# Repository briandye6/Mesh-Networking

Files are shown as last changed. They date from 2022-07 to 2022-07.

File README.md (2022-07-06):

# ENIGMA Mesh Networking Design Project
This repository was designed to be used with the STM32F091RCT ARM Cortex microcontroller.

### Repository Layout:
| File | Purpose |
| --- |:---|
| src/main.c | Contains the all interrupt setup functions, interrupt service routines, and GPS, Battery helper functions |
| src/SPI.c | SPI initialization, write, and read for RFM69HCW Radio and MP2202 TFT Display |
| src/I2C.c | I2C initialization, write, and read for Sparkfun Battery Baby Sitter and SAM-M8Q GPS module|
| src/bluetooth.c|  UART initialization, write, and read for HM-19 bluetooth module|
| src/lcd.c|  Helper functions to communicate with MP2202 TFT Display|
| src/RFM69.c|  Helper functions to communicate with RFM69HCW Radio|
| src/STPswitch.c|  Helper functions to create and facilitate a MESH Spanning Tree Protocol|
| src/list.c| Doubly Linked List Data Structure for forwarding table|

### User Interace: Progressive Web Application
https://enigmaterminal.net/

### Final Design Review Presentation Link with VIDEO DEMONSTRATION
https://purdue0-my.sharepoint.com/:p:/g/personal/dye28_purdue_edu/Ee8eXgqAICREm-nx36Vz36ABuLT1QJ_dSffJ5avcmjQzwg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

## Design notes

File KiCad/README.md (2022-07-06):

# KiCad files for Printed Circuit Board (PCB) Design

### What is KiCad?
KiCad is a free software that facilitates the design and simulation of electronic hardware.

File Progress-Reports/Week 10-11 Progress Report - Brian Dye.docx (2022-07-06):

# Senior Design Progress Report

Student: | Brian Dye | Team: | 20 ENIGMA
Semester: | Spring 2022 | Position: | Team Leader
Week: | 10 and 11 | Hours: | 40

# Progress Description

Over Spring Break, I successfully interfaced the SparkFun Battery Baby Sitter and the Ublox SAM-M8Q GPS module. Both share the same I2C bus. Now we can accurately demonstrate the battery level remaining and show the GPS coordinates of our location:

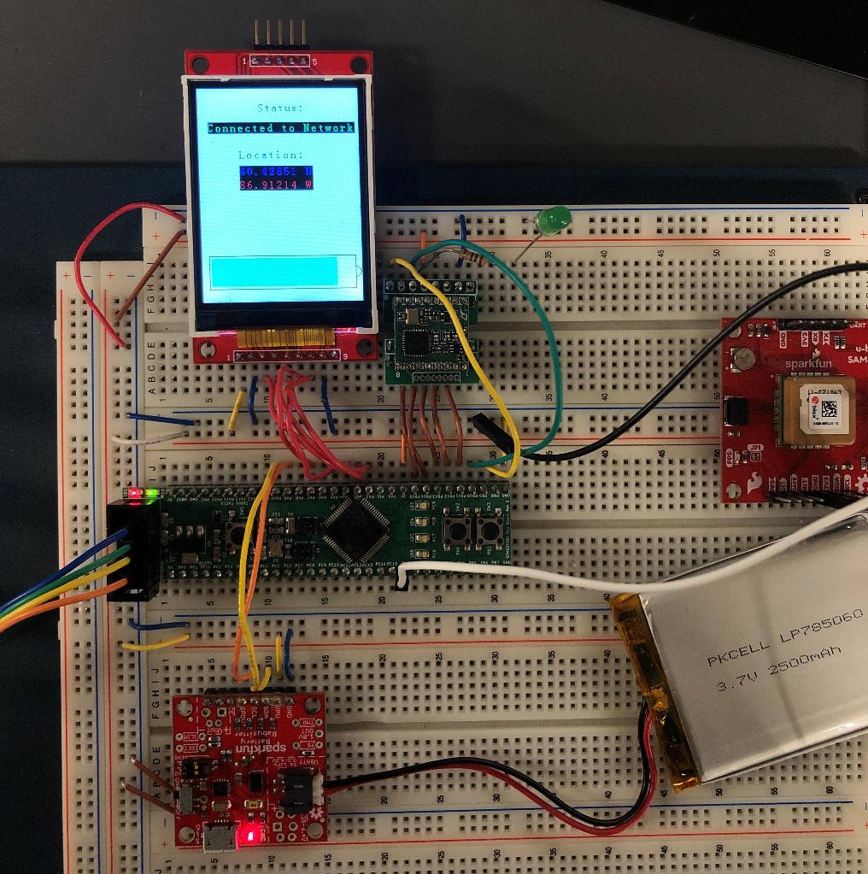
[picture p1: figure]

An issue that I ran into was that I did not have the correct understanding of the frequency that the I2C clock operated at. My initial understanding was that it was operating at 48 MHz which is the same frequency that the STM32F091 clock is operating. The GPS did not “fuss” about the Data Setup Time or Data Hold Time in the I2C communication. However, the Battery Babysitter did. All my calculations for the timing register were incorrect due to my assumption that the I2C clock was operating at 48 MHz. I came to realize the clock is actually operating at 8 MHz from reading the old lecture notes from ECE-362. Once I made the correct changes to the timing register of the I2C, it works flawlessly. Now, the Battery Babysitter and GPS module can share an I2C bus to communicate seamlessly. This accomplishment concludes the serial communication interfacing required to implement the functionality that we desire from each node in our project. Now, I plan to start working on the routing algorithms required to create a self-forming, self-organizing, distributed mobile ad-hoc network.

Module | Function | Serial Protocol
RFM69HCW | Send & Receive Data for mobile network | Serial Peripheral Interface (SPI)
MP2022 TFT LCD Screen | Demonstrate Coordinates, Network Status and Battery Level to User | Serial Peripheral Interface (SPI)
HM-19 | Interface each node with Bluetooth Device | Universal Asynchronous Receiver Transmitter (UART)
Battery Babysitter | Charge and monitor LiPo battery | Inter-Integrated Circuit (I2C)
SAM-M8Q | Provide GPS coordinates | Inter-Integrated Circuit (I2C)

# Printed Circuit Board (PCB)

PCB is done and ordered. We ran into the issue that the edge cut was not properly in the Gerber and Drill files. So, we had to fix the issue and resubmit the files to JCLPCB and it is currently on it’s way. I ordered 10 boards. We have enough modules to make 5 nodes. Extras are for mistakes that potentially occur while soldering components to boards.

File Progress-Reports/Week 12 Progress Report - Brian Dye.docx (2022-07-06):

# Senior Design Progress Report

Student: | Brian Dye | Team: | 20 ENIGMA
Semester: | Spring 2022 | Position: | Team Leader
Week: | 12 | Hours: | 20

# Progress Description

This week I successfully created the push button interrupt for the LCD. Creating this functionality was necessary to reduce power consumption and extend battery life. When the user wants to know network status, battery level, and current GPS coordinates they can push a button which will 1) power the LCD screen and 2) create an external interrupt that sends the most recent network, battery, and GPS coordinates that have been made available by the respective modules. Instead of fetching fresh status updates from modules within the interrupt service routine, I decided to invoke a timer interrupt every 5 seconds to fetch fresh information from each module. Then when the user wants to see information on the LCD screen, it displays the latest information instead of making various serial communications to modules. This proved to be much more efficient.

I also worked on the communication interface between the host device and node. Nathan and I decided to take a conservative approach and send fixed data size packets over Bluetooth. When a packet arrives, it will generate a DMA interrupt which invokes an ISR. In the ISR, the STM32 will read the first n bytes for the command and take appropriate action. This is demonstrated below:

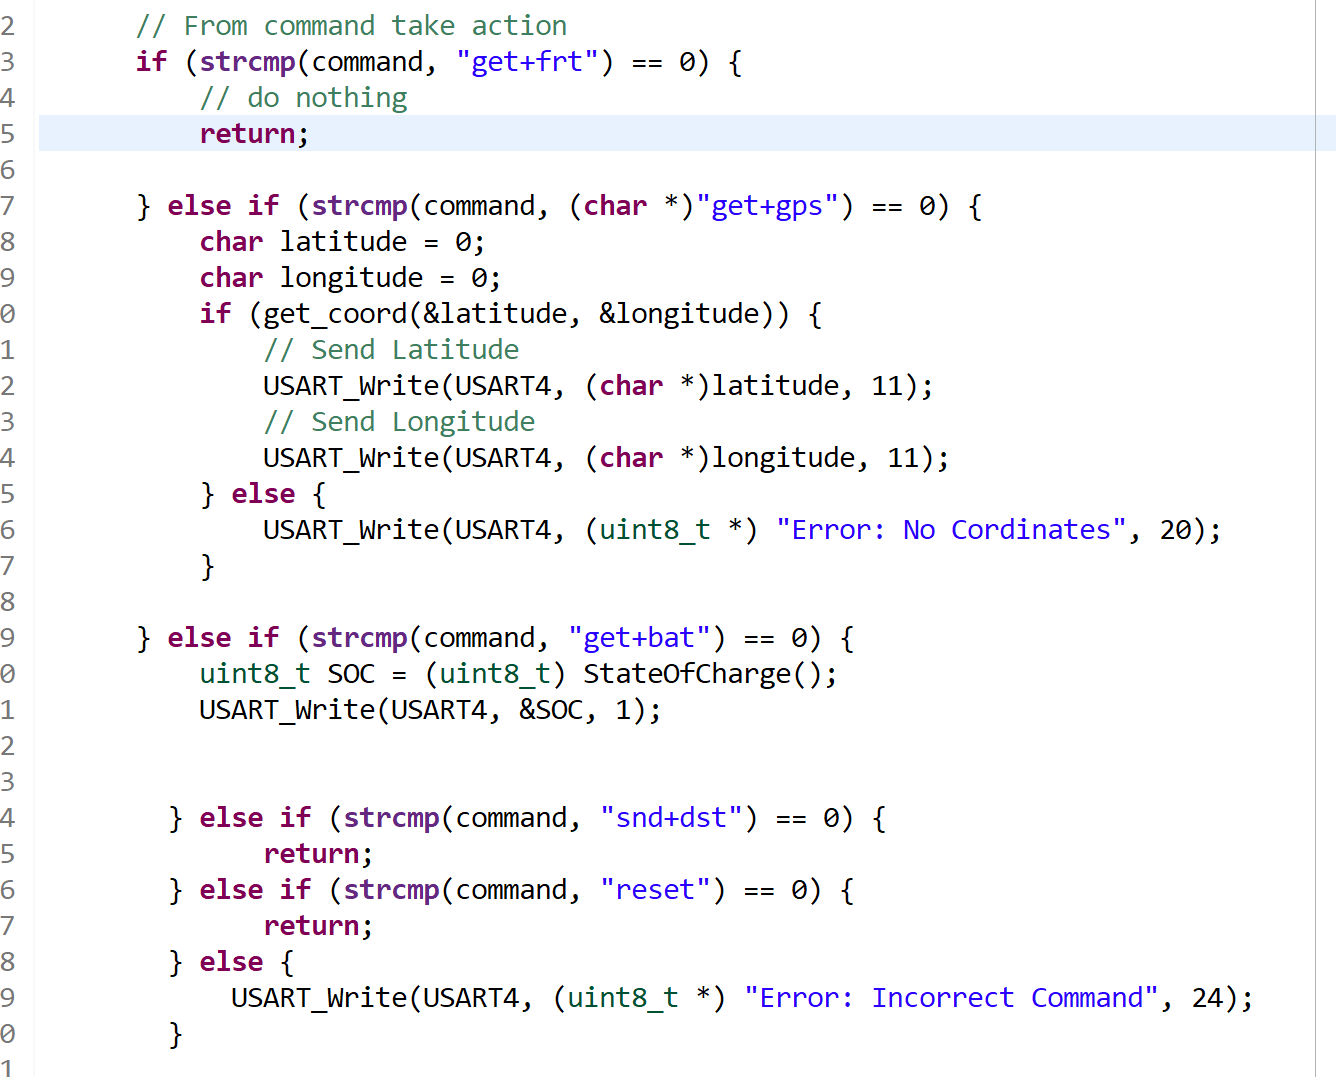
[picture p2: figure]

# Printed Circuit Board (PCB)

PCB has arrived. We have made plans to start soldering the PCB tomorrow on Saturday 04/02/2022. Our current plan is to solder power components, then STM32F0 microcontroller, and finally each individual module. Between soldering each component, we plan on performing tests to ensure proper connections were established.

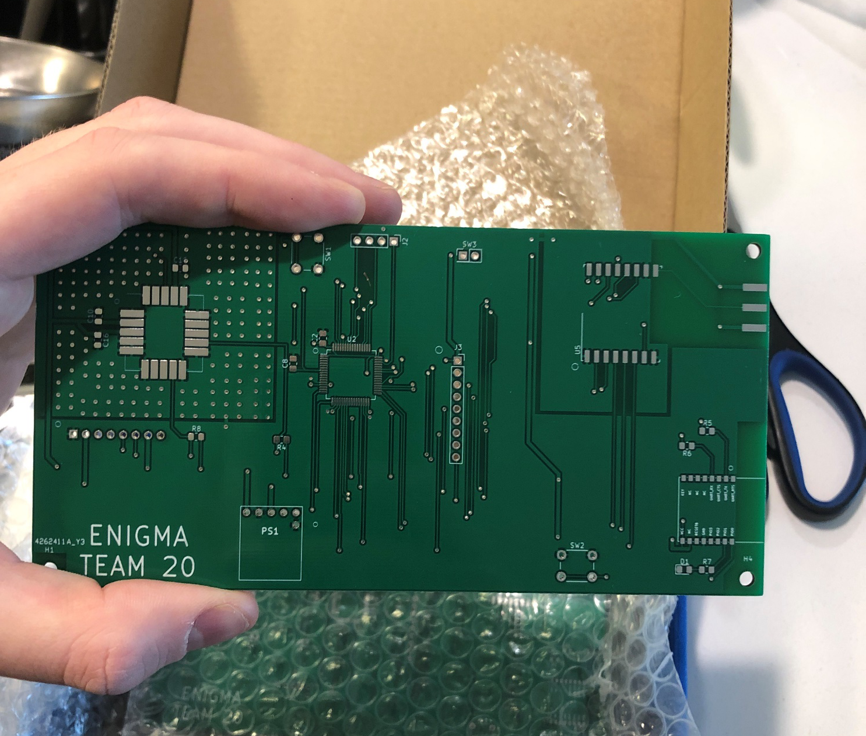
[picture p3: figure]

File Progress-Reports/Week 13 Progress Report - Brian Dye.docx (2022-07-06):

# Senior Design Progress Report

Student: | Brian Dye | Team: | 20 ENIGMA
Semester: | Spring 2022 | Position: | Team Leader
Week: | 14 | Hours: | 30

# Network Progress

I’ve been attempting to get each protocol to work together using the FreeRTOS. I ran into the issue when I attempt to send a packet that was generated by a host device. Right now, I can create a packet using the STM32 and send it to another STM32 via the RFM69. However, there is an issue with the bytes that are received by the host device that introduces a bug in the sending process of the RFM69. This weekend I plan on finding the issue and correcting it.

# Printed Circuit Board (PCB)

We have one board fully soldered. One that is fully solder except for the GPS module. We started soldering a third PCB and Hanyu ran into the issue of not being able to program the microcontroller. Early next week we will debug this issue and troubleshoot the issue. Here is our finished PCB:

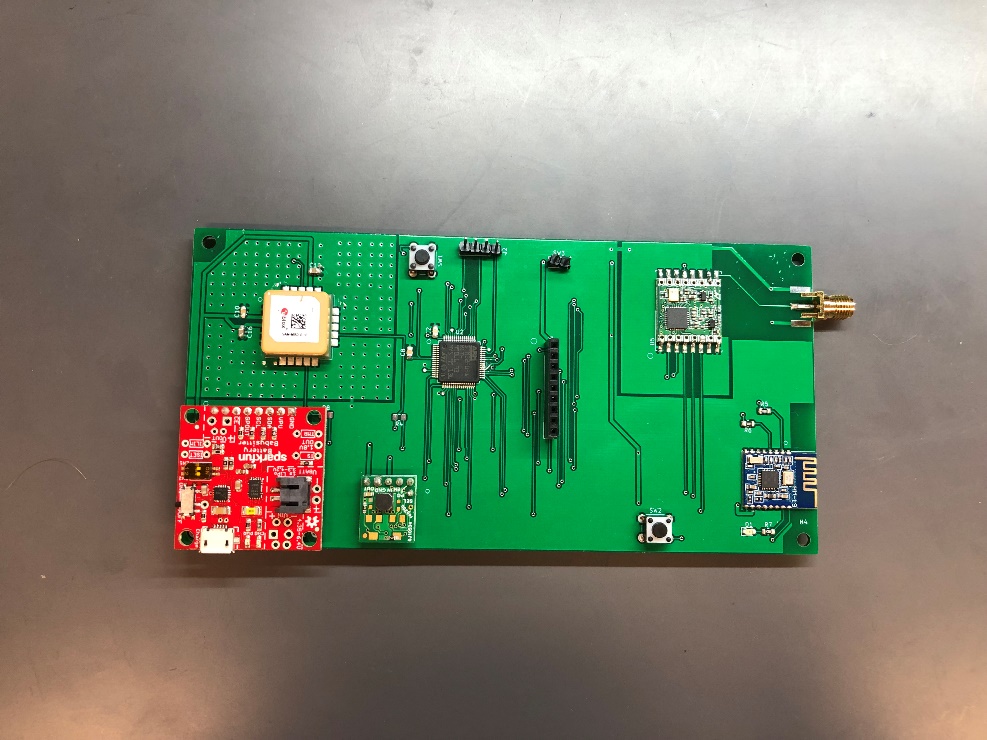
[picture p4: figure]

# Case

Received the case. The PCB doesn’t fit with the current location of the buttons. I spoke with Henry about issues, and we made the appropriate changes and submitted a new design for printing. We increased the height of the case by a ¼ of an inch.

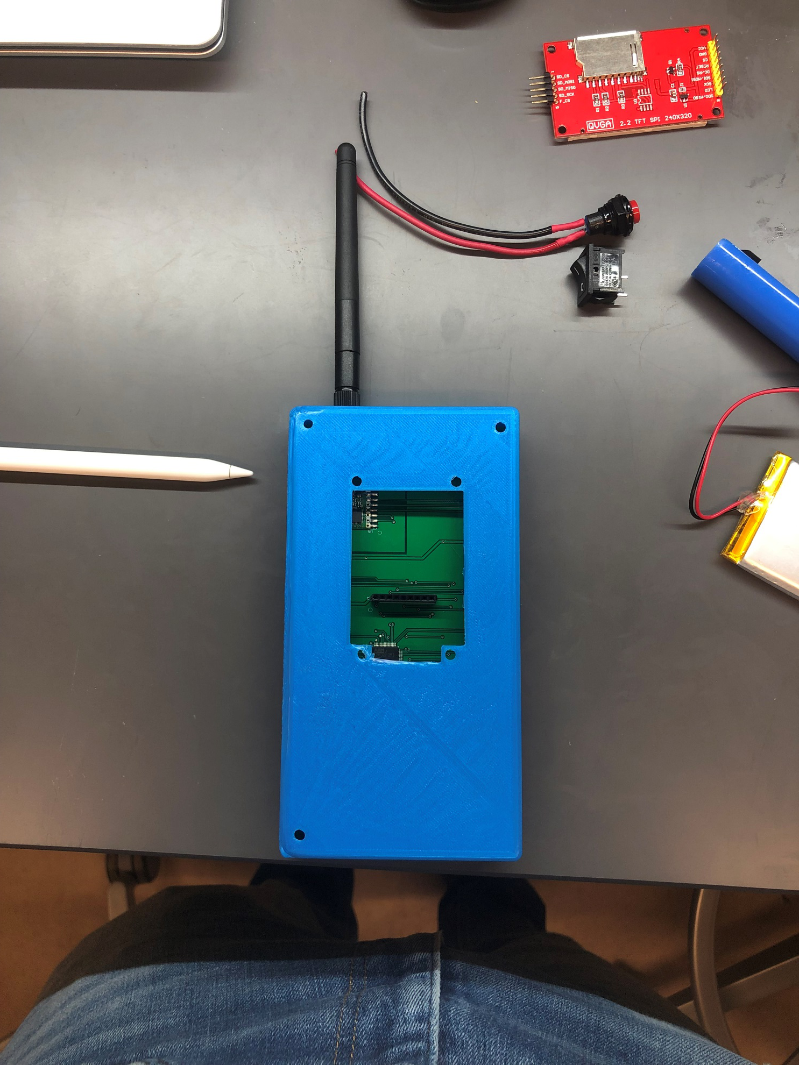
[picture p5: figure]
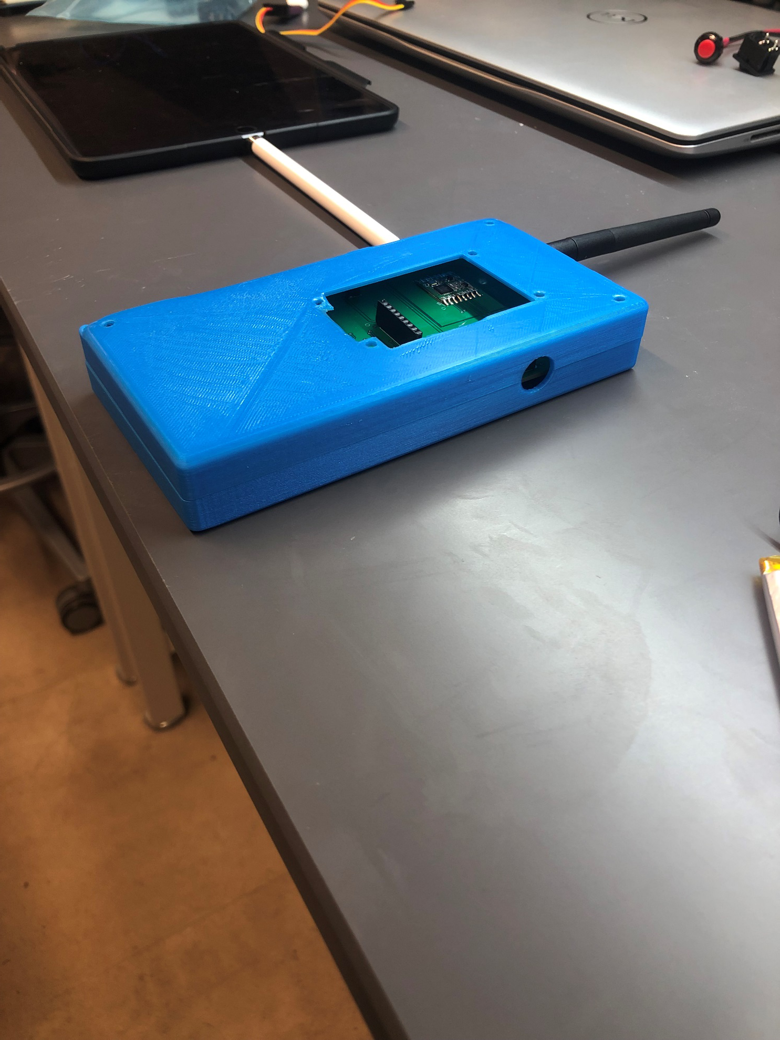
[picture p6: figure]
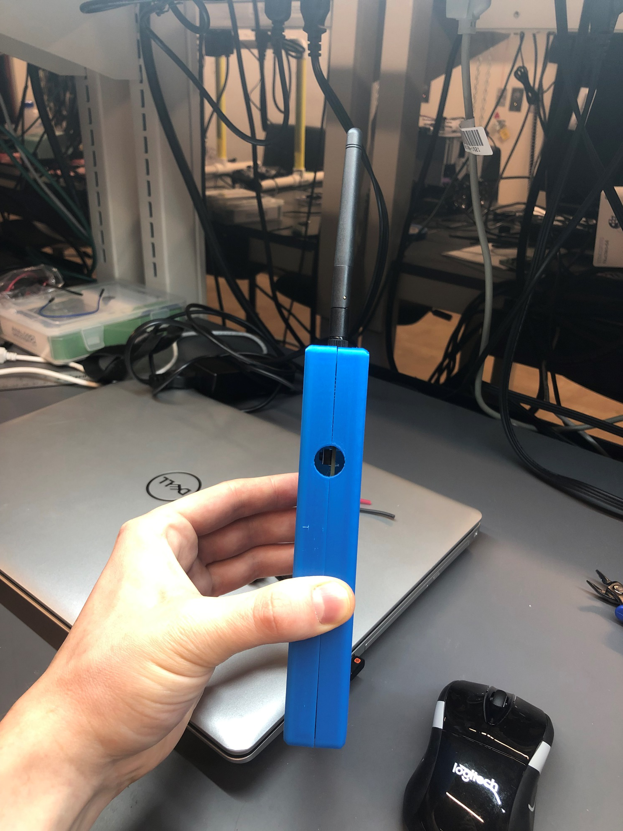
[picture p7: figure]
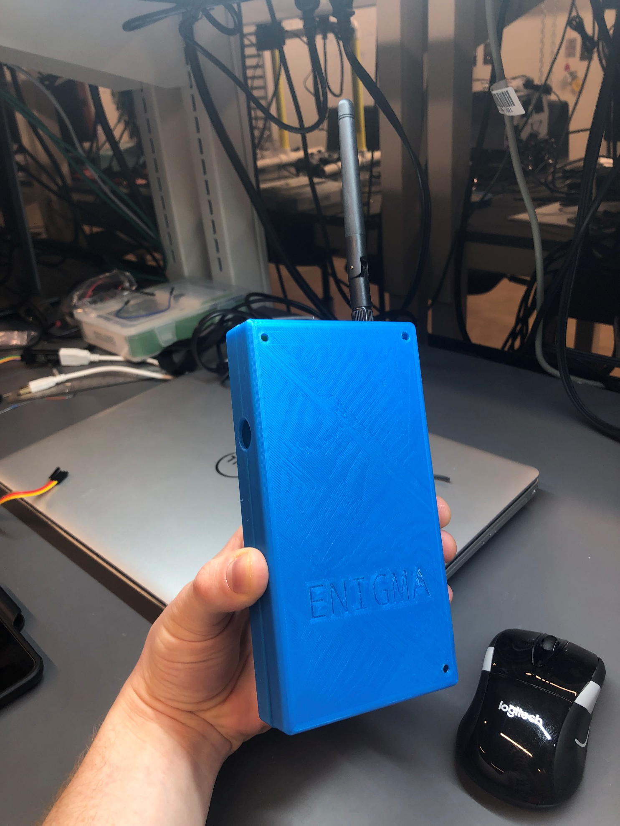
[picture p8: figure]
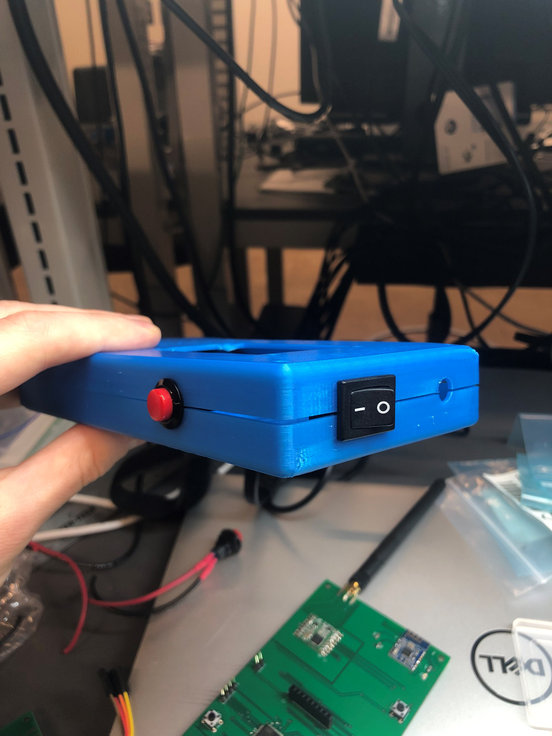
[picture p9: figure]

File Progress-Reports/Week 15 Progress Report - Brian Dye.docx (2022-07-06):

# Senior Design Progress Report

Student: | Brian Dye | Team: | 20 ENIGMA
Semester: | Spring 2022 | Position: | Team Leader
Week: | 16 | Hours: | 35

# Progress

This week was spent getting ready for the Spark Challenge. Most of my time was spent integrating each component to work together. I ensured that packet data was flowing through our system correctly. Packet data needs to transmit properly over UART, be processed by the STM32 for routing and forwarding, and be modulated using the RFM69. My team and I debugged the radio module. We ran into the issue of not sending and receiving consistently. We determined the cause was due to the trace to the SMA connector not being big enough to accommodate the signal strength. We fixed it with a fly wire. I personally ran into the issue of integrating the UART commands. Before the final presentation, I’m thinking about creating simpler commands for the front end to communicate with the back end. Instead, of sending “get+bat” or “get+ft” I think what would be easier would be sending a number that is associated with a functionality instead of sending a string that is associated with a functionality.

# Case

I developed the strategy for mounting the PCB inside the case. Here is the final result and my team and I at the Spark Challenge:

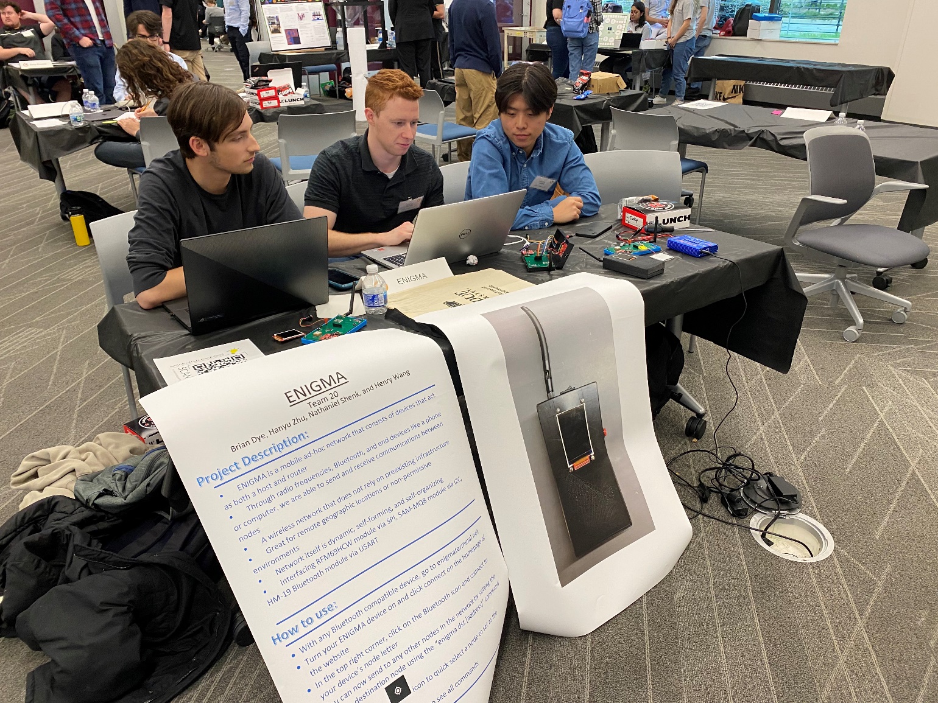
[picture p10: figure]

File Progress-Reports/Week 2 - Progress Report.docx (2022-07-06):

# Senior Design Progress Report

Student: Brian Dye Semester: Spring 2022

Week: 2

Team: 20 ENIGMA

Position: Team Leader

Hours: 20-30

# Progress Description

This week was used to solidify our plans to accomplish the goals of our project. During our lab on Wednesday, my team and I discussed the pros and cons of utilizing a second microcontroller to carry some of the responsibilities of the network stack. We were concern with the battery consumption of using 2 microcontrollers to accomplish our project goals. I consulted with a past professor on his thoughts about utilizing a second microcontroller and I learned that the interfaces that would utilize the wireless land area network implement the functionality of the network stack that we were going to implement on the second microcontroller. After realizing this my team can utilize one microcontroller instead of relying on two which saves money, power, and time designing. My team plans on utilizing one of the following designs:

Figure 1: Potential Microcontroller Layout

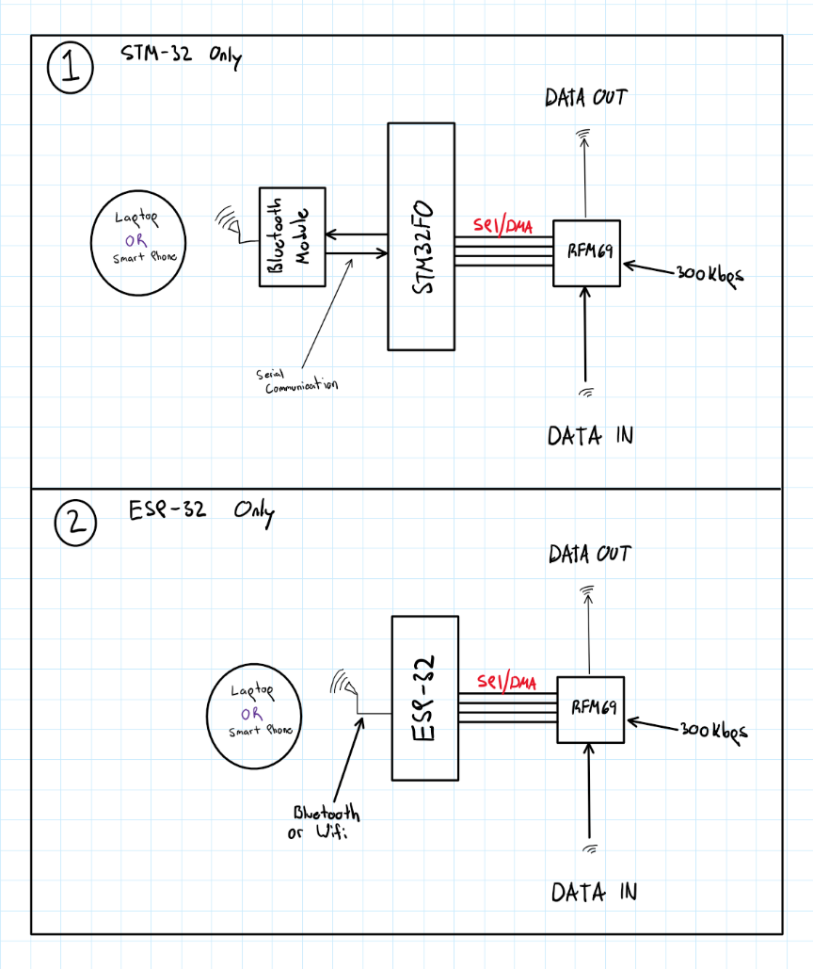
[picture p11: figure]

# Individual Responsibilities

During this week, my team also established individual responsibilities that will contribute to the success of achieving our project goals. They include the following:

Team Member | Individual Responsibilities
Brian Dye | Implement the embedded networking protocols of the wireless land area network. Write the embedded real-time operating software for a packet switched network. Assist Henry in the serial communication of the RFM-69 radio module and microcontroller device. Assist Nathan with developing the applications that will utilize our LAN.
Hanyu Zhu | Implement the embedded software necessary to facilitate a wireless packet switched network. Assist Henry & Nathan with embedded software development and user interface
Henry Wang | Responsible for developing the ecosystem serial communication software that communicates with the RFM-69 & Bluetooth module
Nathan Shenk | Responsible for implementing the application(s) that will utilize the mobile ad-hoc network. Potential applications include: (1) Text messaging services (2) Satellite view of the geographical locations of each node on the network (3) Audio services (4) File Transfer

# Winter Break Progress (Pre-Semester)

Over the 2021 – 2022 winter break, I brainstormed about potential microcontrollers that could be used in our implementation. In ECE-36200, we utilized the STM32F0 microcontroller. It’s a microcontroller everyone in the group is familiar with. It’s programmed in C and comes with an ecosystem of timers, interrupts, general purpose input and output mechanisms, and serial communication protocols that include: UART, I2C, SPI, and DMA. It’s main clock operates at 48 MHz. In ECE-40862, we utilized the ESP-32 that comes with much more computational power and interfaces such as WiFi and Bluetooth. It can also be programmed in MicroPython. It has a Single/Dual Core microprocessor and advanced ultra-low-power management. I also wanted to find a radio module for the physical layer of the network stack that will allow us to communicate at distances of 500-600 meters at the highest bandwidth possible. I found the RFM-69HCW radio module. It’s a small device that communicates with a microcontroller via an SPI connection. It has a range of 500 meters and a maximum bitrate of 300 kbps = 37,500 Bytes/second. It operates in the ISM frequency spectrum (915 MHz) that is reserved for industrial, scientific, and medical purposes. I formulated how the concepts that we learned about in Introduction to Computer Communication and Networking (ECE-46300) can be utilized to create a Mobile Ad-Hoc network. What industry standards can we use to create the Data Link Layer? What industry standards can we use to create reliable communication (Transport Layer)?

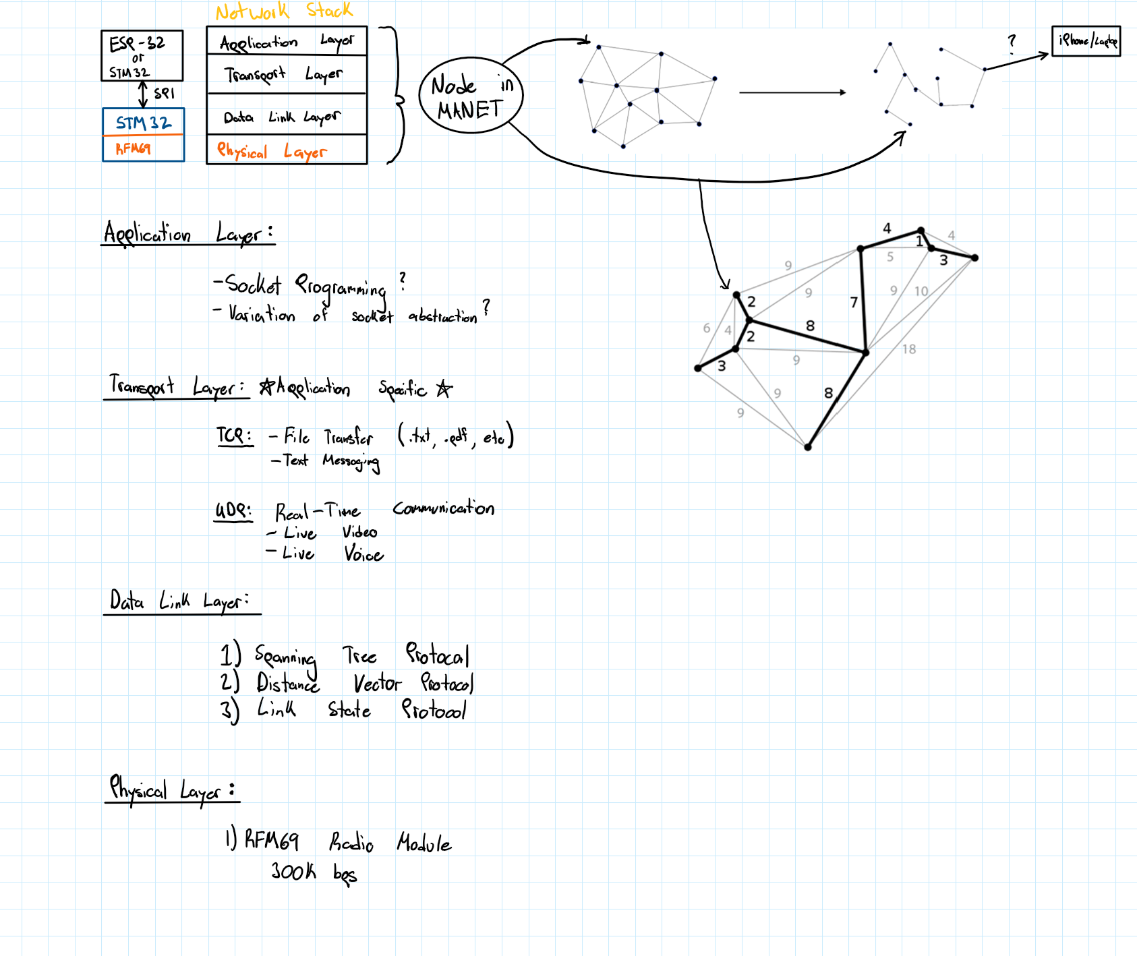
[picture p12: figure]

Figure 2: Microcontroller Network Stack Responsibilities

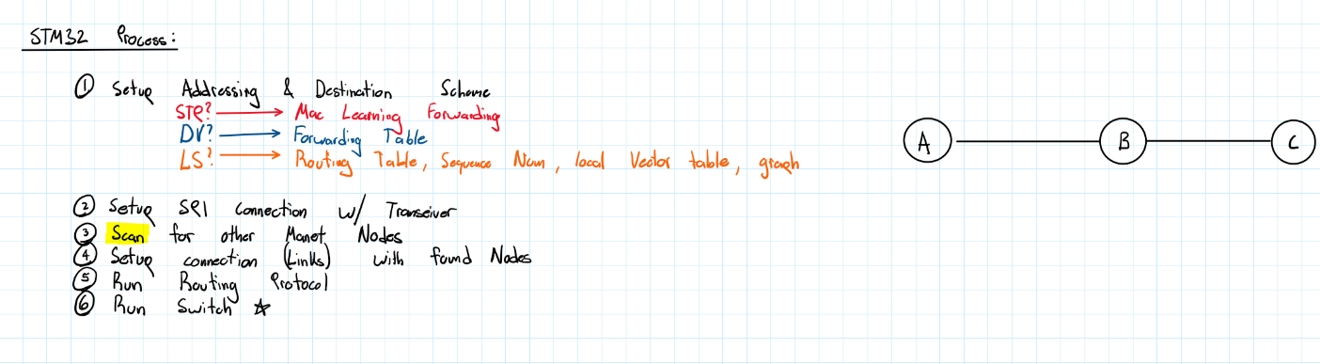
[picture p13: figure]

I also wanted to gain an understanding of the real-time scheduling that would be needed to maximize throughput in our wireless land area network. What would the STM-32 be responsible for? What would the ESP-32 be responsible for? How would the STM-32 communicate with the ESP-32? What would the device look like?

Figure 3: Process of STM-32 setup

My concern was concern was the rate at which data can be processed. CPUs on embedded microcontrollers sacrifice speed for general computation. To overcome this, I wanted to utilize Direct Memory Access (DMA) in conjunction with Serial Peripheral Interface (SPI) to reduce the workload of each Central Processing Unit at each node. I wrote C code that would enable the ESP-32 to directly write via SPI into a send buffer located in the STM-32’s memory. The STM-32 would then process the data into packets and wrap them with Data Link Headers and send the packets to the RFM-69 radio module. Below is a depiction of the abstraction protocol between the ESP-32, STM-32, and RFM-69 using SPI and DMA.

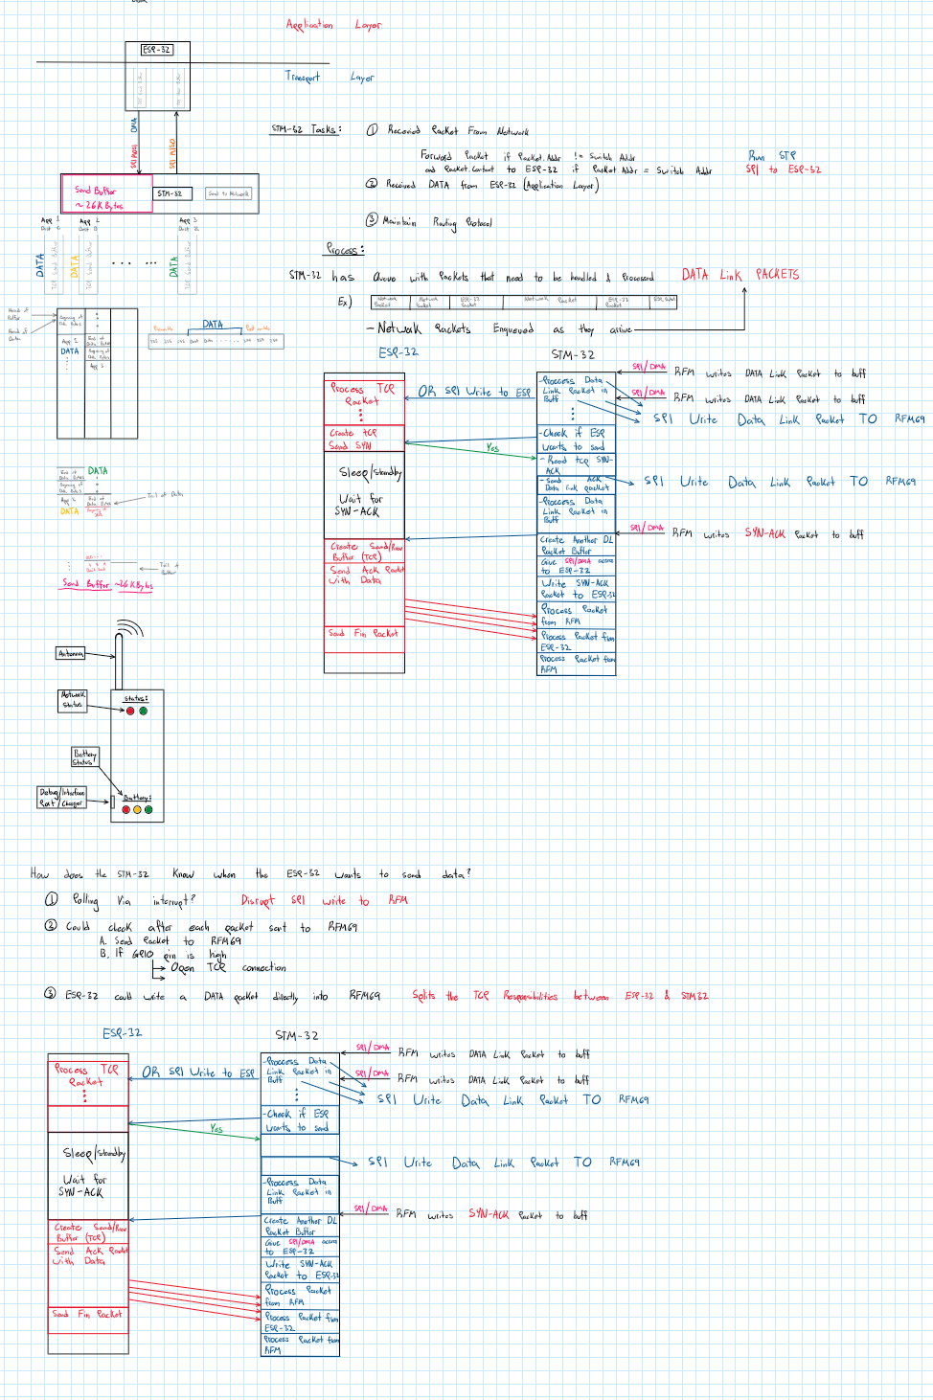
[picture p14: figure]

Figure 4: Communication between modules

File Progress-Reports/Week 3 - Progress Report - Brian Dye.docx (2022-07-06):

# Senior Design Progress Report

Student: | Brian Dye | Team: | 20 ENIGMA
Semester: | Spring 2022 | Position: | Team Leader
Week: | 3 | Hours: | 20-25

# Progress Description

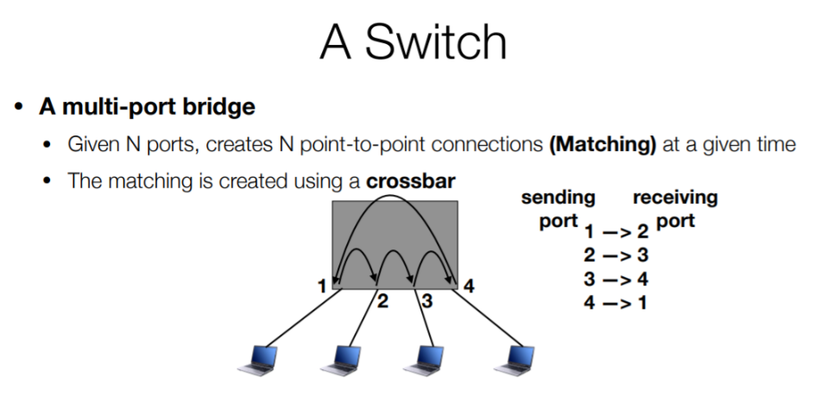
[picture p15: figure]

During this week, I review our past project on the Spanning Tree Protocol. I came to understand that we will need to make modifications in the algorithms we used in our project due to our objective of creating a wireless land area network. Our past project that utilized the Spanning Tree Protocol operated on the assumption of a wired ethernet connection to the ports on the switch. This is illustrated in Figure 1:

Figure 1: Switch Diagram

For each switch in our project, we don’t have data arriving and exiting through multiple different ports. We have 1 point of entry, and 1 point of exit. To overcome this problem, I believe the solution is to abstract “ports” with the MAC addresses of the sender to each switch. This abstraction is illustrated in Figure 2:

Wireless Switch

Figure 2: MAC address substitution for port

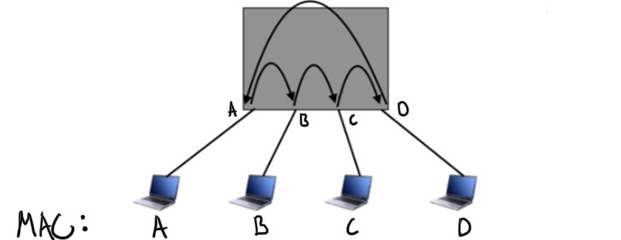
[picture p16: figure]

By knowing which neighboring node a packet was received from, we can turn the abstraction of mapping ports and links to sender addresses and links.

# Ordering Parts

This week my goal was to order electronic components that we can prototype on the ESP-32 development board and use on our Printed Circuit Board. The list of components is the following:

1. 4 Duck Radio Antenna’s
2. 3-4 RFM-69 Radio’s
3. 4 SMA Connectors
4. 4 GPS SAM-M8Q modules

We will be using antennas/connectors to increase the RFM-69 wireless transmission signal’s range and reliability. The GPS modules will used for a satellite application that demonstrates network status and node locations.

# RFM-69 Radio API

I wanted to make sure that team members have a clear vision of their individual responsibilities. I spoke with Hanyu and Henry about the expectations of interfacing with the RFM-69 radio module. I gave them the following RFM-69 API to implement to facilitate creating a wireless network:

RFM69(addr) | Create an RFM69 object with address addr Instance Variables: - SPI object associated with RFM-69 - Node Addr = addr Configure the RFM-69 with the highest bitrate and transmission power consumption
void sendTo(self, Addr, DATA) | Send Data to Addr using the RFM-69
bytearray recv(self) | Get the data from the receive buffer of RFM-69
void writeToReg(self, register, value) | Write value to register in RFM-69
int readReg(self, register) | Read value from RFM-69 register
bool checkRecv(self) | Check if RFM-69 has received data
void lowerPowerMode(self) | Turn on the low power features of RFM-69
list search(self, seconds) | Return the address(es) of other RFM69’s broadcasting using the same network ID

Example API usage:

I helped Henry and Hanyu research previous implementations for interfacing with the RFM-69 to help them create our own implementation that will align with our objective of creating a wireless land area network. We found several open source RFM-69 modules written in variety of different programming languages.

# Network Applications and User Interface

I spoke with Nathan about the react native application that will implement a couple different sub applications that utilize the mobile ad-hoc network. We discussed the welcome page of the application and agreed on prompting the user to enter an identifier, and then allowing them to select which sub application they would like to use. Nathan and I also spoke about companies that occupy similar markets such as goTenna which has civilian and military applications in mesh networking.

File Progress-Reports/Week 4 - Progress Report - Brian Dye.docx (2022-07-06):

# Senior Design Progress Report

Student: | Brian Dye | Team: | 20 ENIGMA
Semester: | Spring 2022 | Position: | Team Leader
Week: | 4 | Hours: | 15

# Progress Description

This week my team learned that we cannot use MicroPython to accomplish our PSSCs. As a team, we contemplated whether we should complete our project using the familiar STM-32 microcontroller and the System Workbench integrated development environment (IDE) or attempt to program the ESP-32 in C using an IDE we are unfamiliar using.

I also spent quite a bit of time last weekend (1/29/2022) attempting to setup the SPI connection between the ESP-32 microcontroller and the MSP2202 TFT LCD display using MicroPython. I re-read the documentation and lab manuals from ECE-36200 to gain a better understanding of how to communicate with the LCD display effectively. I came to understand that the LCD requires a special SPI protocol that switches between 8-bit and 16-bit word transfers, along with setting and unsetting pins on the LCD screen to distinguish between communicating register updates and data (screen) updates. While I was setting up communication between the ESP-32 and LCD screen, I ran into an issue with the ESP-32 not being able to switch between sending 8-bit words and 16-bit words. When I attempted to de-initialize the SPI connection to change the word size, I received the following error:

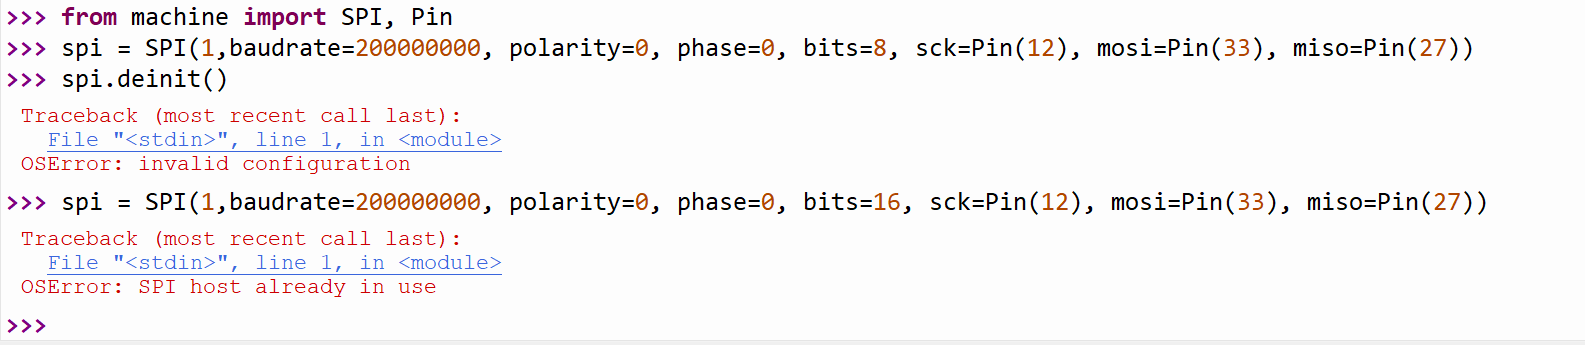
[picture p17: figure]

I could not find a solution online and I believe the problem lies within the boundaries of MicroPython (which would further demonstrate why MicroPython is insufficient). If my team decides to utilize the ESP-32 using C, I am curious to see if we run into the same issue.

# Electronic Components

My team is incredibly fortunate that ECE-47700 staff has many of the electronic components that I planned on ordering last week already in stock. This week I checked out 2 GPS modules and 2 Duck antennas. I also learned that the ECE-47700 has Bluetooth modules if my team decides to use the STM-32 and they also ordered SMA connectors. Because the ECE-47700 staff already has these components in stock, this saves my team approximately $200.00. My team can now allocate our budget to other pieces of equipment and possibly create more individual devices.

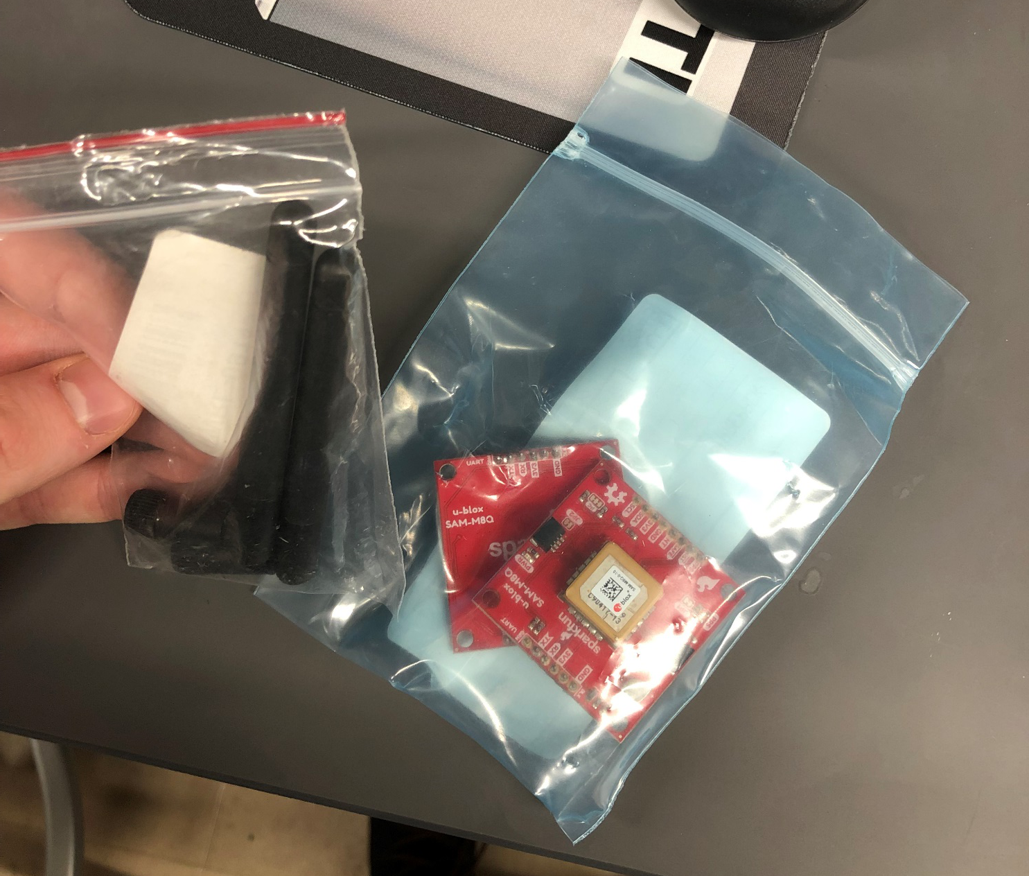
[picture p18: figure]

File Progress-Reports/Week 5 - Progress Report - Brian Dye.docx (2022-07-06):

# Senior Design Progress Report

Student: | Brian Dye | Team: | 20 ENIGMA
Semester: | Spring 2022 | Position: | Team Leader
Week: | 5 | Hours: | 15

# Progress Description

This week I interfaced the STM32 with the MSP2022 TFT LCD screen. I used the family reference manual and data sheet of the STM32F091RCT to determine what pins to map the SPI functionality to. I also created the image that we plan to display. A picture is demonstrated below:

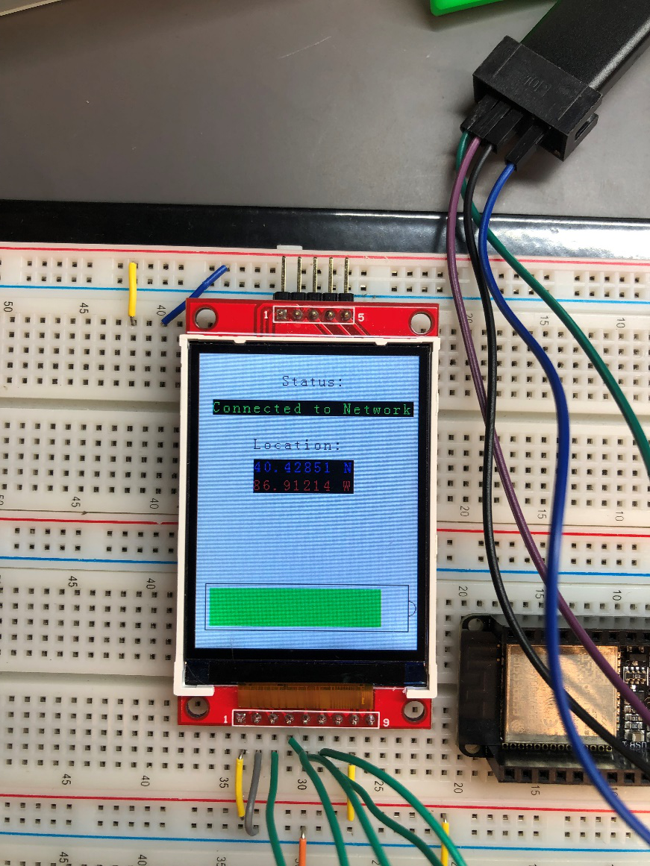
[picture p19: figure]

I created a strategy for how my team will utilize the LCD display. First, we plan on creating a push button interrupt that turns the LCD screen on. Using a push button interrupt, we can save power by not leaving the LCD screen on which saves us an enormous amount of power. Second, I created the image for the LCD display. My plan is to display the network status (connected or not connected) and the last GPS reading from the SAM-M8Q. Finally, I want to display the battery status of the device using a battery icon which is demonstrated in the photo.

This week, I also worked on setting up the RFM69 Radio module. I once again referenced the data sheet and family reference manual to determine which pins on the STM32 I can use to communicate with the RFM69 module using SPI. I had to select an SPI channel that was different from the channel I selected to communicate with the LCD screen. We worked on setting up the RFM69 for a few hours and my team and I had to refresh our understanding of utilizing SPI to communicate with peripheral devices. This weekend, I plan to continue interfacing the STM32 with the RFM69.

# PSCC Finalize

My team and I came to a final understanding our PSCCs. We made them broader and finalized the hardware periphals that we plan on utilizing to achieve our project goals. Instead of using the HC-05 bluetooth module, we plan on using a lower powered and newer module called the HM-19 which utilizes BLE and comes with an app for testing. Instead of using the Spanning Tree Protocol to route packets, we will implement a more generalized best-effort data link layer protocol.

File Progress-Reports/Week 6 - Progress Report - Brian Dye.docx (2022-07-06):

# Senior Design Progress Report

Student: | Brian Dye | Team: | 20 ENIGMA
Semester: | Spring 2022 | Position: | Team Leader
Week: | 5 | Hours: | 25

# Progress Description

This was a successful week. My team and I were able to interface with the RFM69HCW radio module using SPI. This is the most important PSCC we have and it’s the most important interface to successfully create a mobile ad-hoc network. While I was setting up the SPI connection between the RFM69 and STM32 microcontroller I wanted to create objectives that ensure the SPI configuration is correct and accurate. So, I gave my team the objective of 1) successfully writing to a register on the RFM69 and 2) successfully reading from a register on the RFM69. Achieving these two goals will allow us to utilize all the functionality that the RFM69 provides such as sending data, receiving data, determining signal strength, etc.

I created a system that would allow us to test our achievement of these goals. I set up a process that attempted to write an 8-bit value to the address register in the RFM69. Then immediately read from the same register. The process looks as follows:

char * address = "ABCDE";

for (int i = 0; i < 5; i++) {

RFM69_setAddress((uint8_t) address[i]);

regValue = RFM69_readReg(REG_NODEADRS);

}

If successful, on the first iteration of the loop the STM32 should write the value 0x65 (‘A’) to register 0x39 on the RFM69 and then read the value 0x65 from register 0x39. On the second iteration of the loop, the STM32 would write the value 0x66 (‘B’) to register 0x39 on the RFM69 and then read the value 0x66 from register 0x39 on the RFM69.

The issue can be further demonstrated using the following table:

Iteration | Value written to address register | Value read after writing address value
1 | ‘A’ (0x65) | NULL (0x00)
2 | ‘B’ (0x66) | ‘A’ (0x65)
3 | ‘C’ (0x67) | ‘B’ (0x66)
4 | ‘D’ (0x68) | ‘C’ (0x67)
5 | ‘E’ (0x69) | ‘D’ (0x68)

So, every time I attempted to write a value to a register, I wouldn’t be able to read the correct byte until I sent another byte to the register. I probed the SPI channel using an oscilloscope, and I came to understand that even though the SPI is configured for an 8-bit word, the SPI channel is generating a clock signal for another 8-bits after 8 bits of data is sent out. This issue is demonstrated in the following figure:

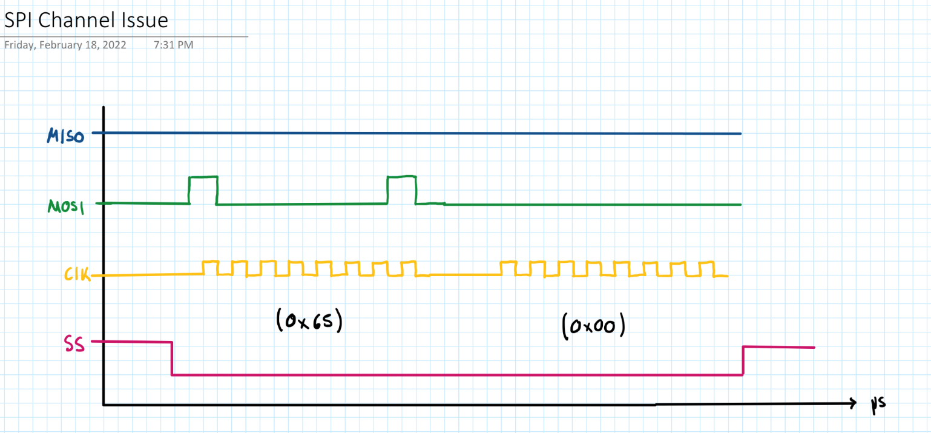
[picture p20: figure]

We fixed the issue using a special cast on the data register of the SPI channel:

*(uint8_t *)&(SPIx->DR) = txBuffer[i];

This told the compiler to treat the 16-bit SPI data register as an unsigned 8-bit value. This transformed the SPI channel activity into exactly what we need:

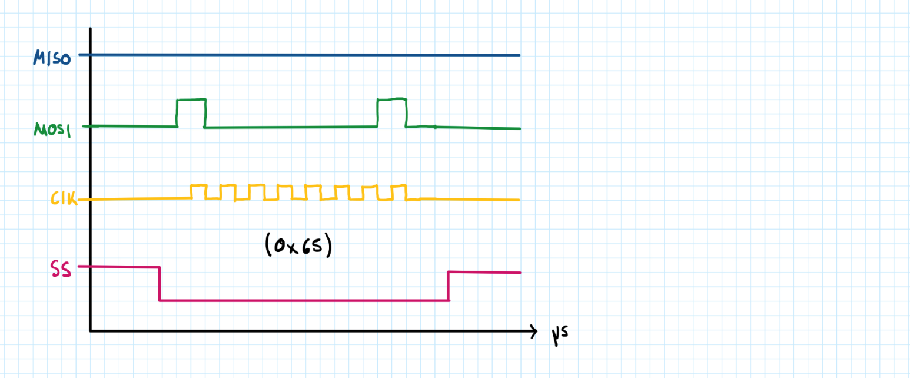
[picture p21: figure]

Now we can successfully write to an RFM69 register and read from an RFM69 register which gives us complete access to all the functionality that the RFM69HCW provides.

# Bluetooth Module HM-19

I worked extensively with Henry and Nathanial to configure the HM-19 bluetooth module using UART. We setup the UART pin connection to the STM32. As well as setup the UART configuration registers on the STM32. However, there is still work that needs to be done. We were unable to receive a response from the HM-19. I believe the issue lies in the configuration of the UART on the STM32. It’s diffcult to understand the required configurations of the HM-19 and what it expects from the UART connection because the documentation isn’t very good. This weekend, and next week I plan on using the oscilloscope to gain an understanding of the electrical oscillations that are occuring during the UART communication to debug the problem.

I’ve been contemplating using the HC-05 Bluetooth module. It has much better documentation. However, it’s less power efficient. I haven’t been able to find much information online for the HM-19 and the manufacturer information is sparse.

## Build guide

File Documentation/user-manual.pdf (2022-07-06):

# ECE 362 STM32F091 Development Board User Manual

Rev 1.01
February, 2021

## Features

- STM32F091RCT6 microcontroller with 256 KB Flash memory, 32 KB SRAM in an LPQF64 package
- External programmer socket to configure and supply power to the system
- Selectable 8 MHz and 32.768 kHz
crystal oscillators or I/Os routed to
header pins

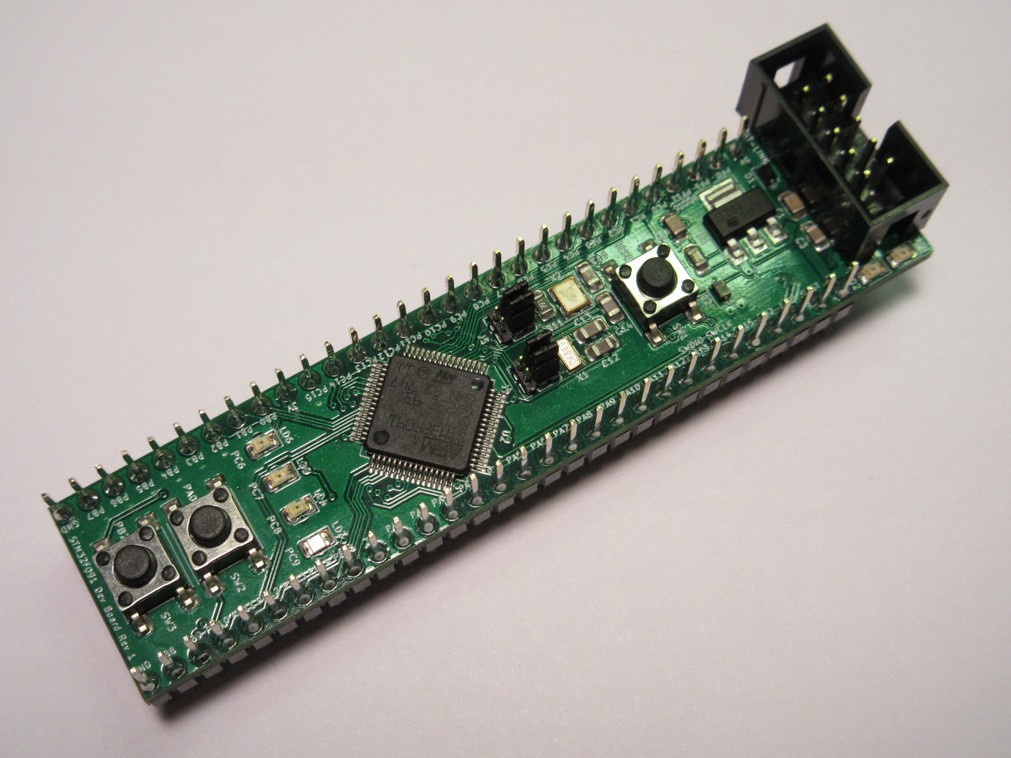
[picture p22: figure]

- Breadboard-friendly header pins for all I/O pins on the STM32F091RCT6
- External power supply pins for 3 V and 5 V
- Two microcontroller-readable push buttons: SW2 (PA0) and SW3 (PB2)
- Two power indicator LEDs (red: 5 V, green: 3 V)
- Four microcontroller-writable LEDs:
- LD6 (PC6) Red LED
- LD5 (PC7) Yellow LED
- LD4 (PC8) Green LED
- LD3 (PC9) Blue LED

## Inserting the Development Board into a Breadboard

When the development board is centered on a typical solderless breadboard with a 0.3” trough, it leaves two holes on either side to connect wires. Use a thick wire to pre-widen the holes where the development board will be plugged in. Place the board on the holes and push it into the breadboard by pressing on the reset and user push buttons. Avoid pressing on the other electronic components.

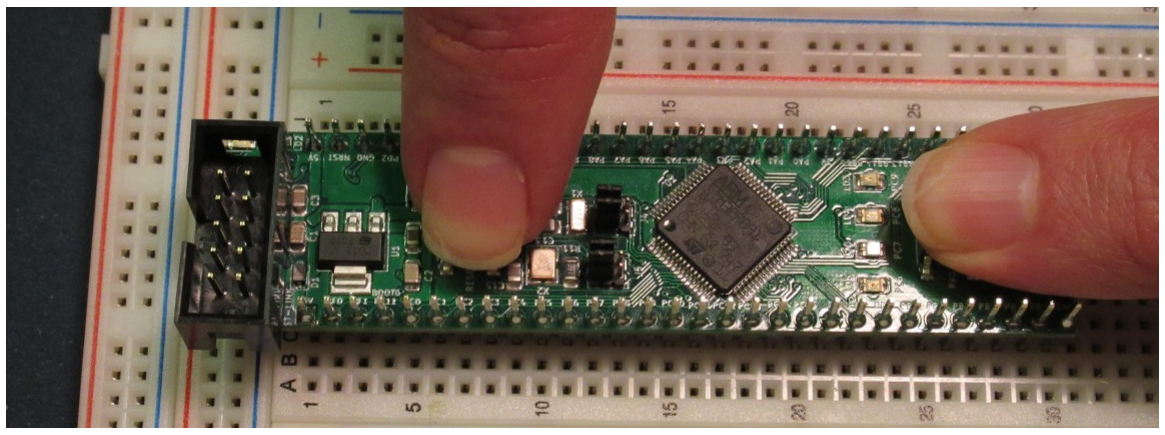
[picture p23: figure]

## Removing the Development Board from a Breadboard

To remove the board from a breadboard, gently pry one side at a time a short distance with a thin, nonmetalic wedge such as a wooden popsicle stick or tongue depressor. Do not pull one side entirely out of the breadboard or the pins on the other side will be bent.

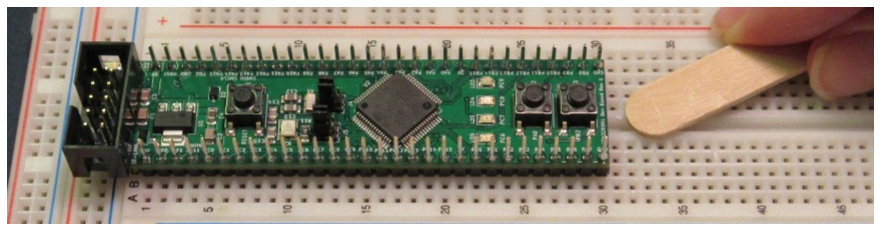
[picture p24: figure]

## Attaching the Programmer

A 10-pin ribbon cable connects the programming header of the development board to an ST-LINK V2 USB programmer with the proper pin configuration. A 28 gauge ribbon cable will supply enough power for the development board as well as 100 mA of power for external devices connected to the development board. There are two kinds of ST-LINK V2 USB programmers. A programmer with the proper configuration is shown in the image with the check mark. A different programmer pin configuration will neither damage the board nor make it function.

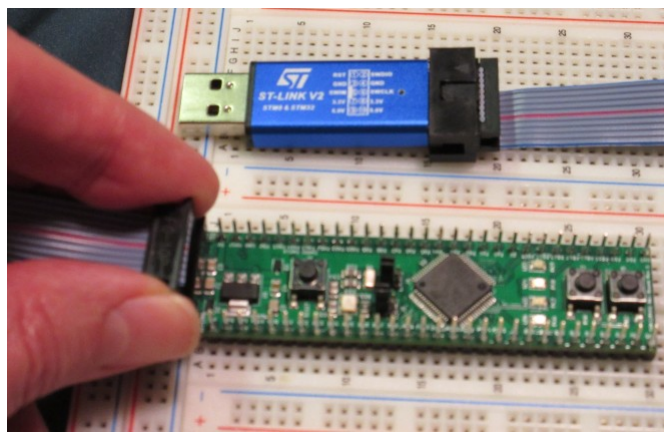
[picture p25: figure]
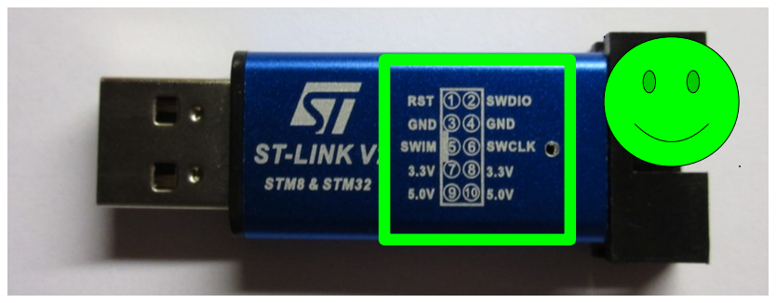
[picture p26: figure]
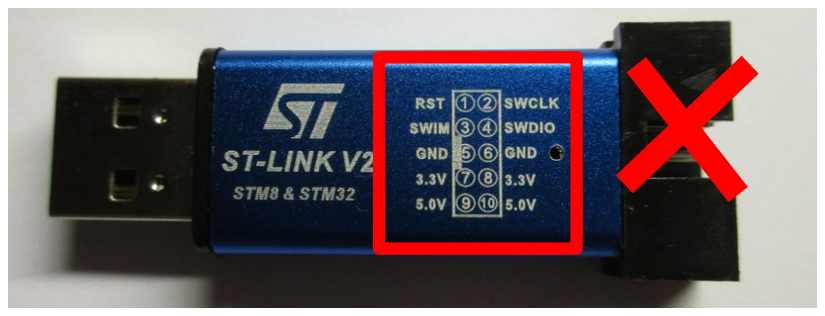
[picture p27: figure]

To connect a programmer with the wrong pin configuration, use the four wires that came with the adapter to match each wire in the programmer with the corresponding pin on the development board. Connect a either of the two 5V pins, either of the two GND pins, SWDIO, and SWCLK.

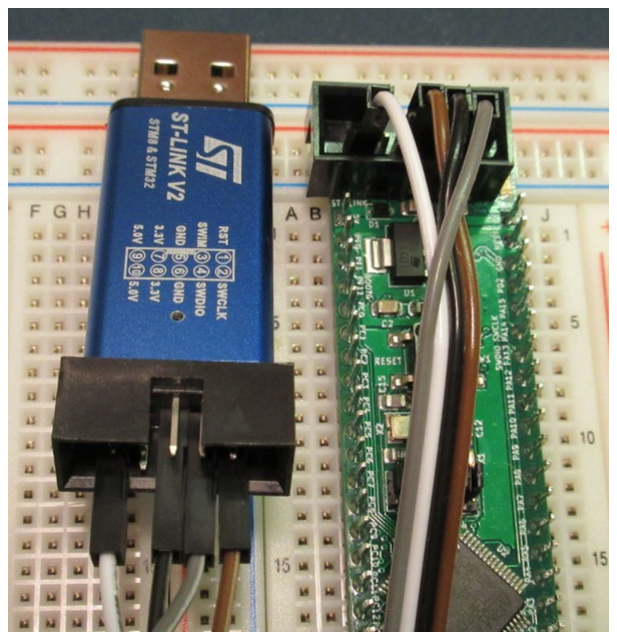
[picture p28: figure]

Everyone involved with the design, manufacture, and distribution of this development board learned of the
existence of a second configuration of programmer a few
days before the lab kits shipped to students. We learned this

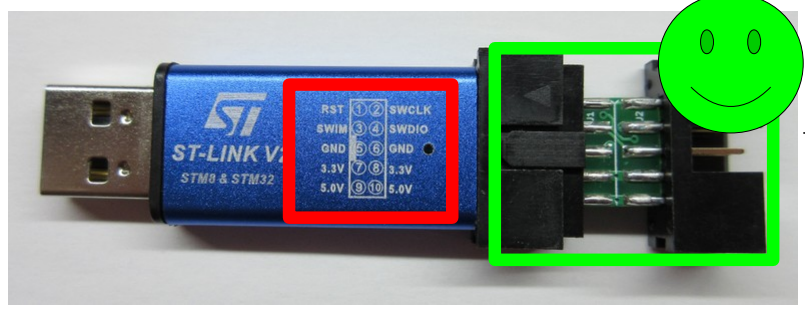
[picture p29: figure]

because none of the programmers worked. (Why should there be two different pin configurations of the programmers?) It was too late to do anything that would not greatly delay the delivery. We’re building an adapter to correct the pin order. You will receive the adapter as soon as one is built for you.

"Wrong" programmer header

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
Development board header

## Using the Development Board

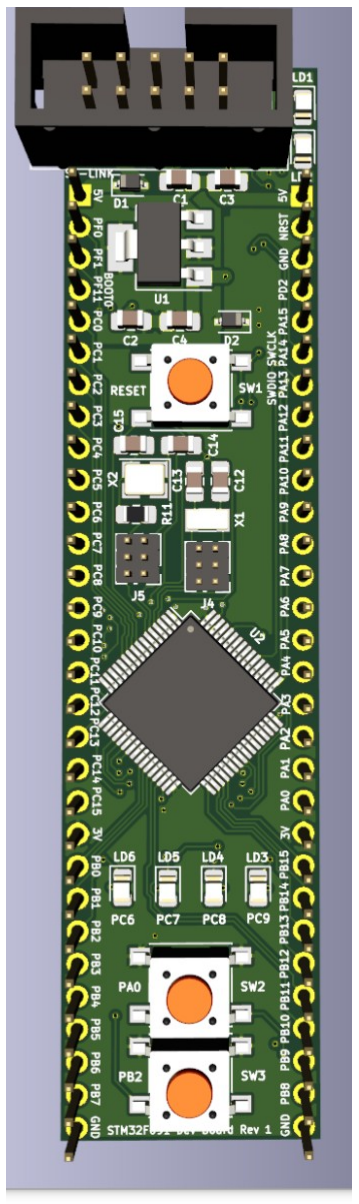
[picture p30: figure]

When the development board is properly powered, the red (LD1) 5V indicator and the green (LD2) 3V indicator LEDs near the programming header will illuminate.

## Push Button Inputs

The RESET (SW1) button resets the the microcontroller on the development board. There are two program-readable buttons:
- SW2 is connected to Port A, pin 0 of the microcontroller via a 1K series resistor.
- SW3 is connected to Port B, pin 2 of the microcontroller via a 1K series resistor. Each push button sets the microcontroller pin high. There is no pull-down resistor to pull the pin low when a button is released. Use the internal pull-down resistors in the microcontroller.

## LED Indicators

In addition to the power indicator LEDs, LD1 and LD2, four program-writable LEDs are illuminated by a high voltage on the corresponding microcontroller pin.
- LD6 is connected to Port C, pin 6.
- LD5 is connected to Port C, pin 7.
- LD4 is connected to Port C, pin 8.
- LD3 is connected to Port C, pin 9.
Less than a milliampere of current is needed to illuminate these LEDs, so they do not interfere with using the pins for general-purpose interfacing.

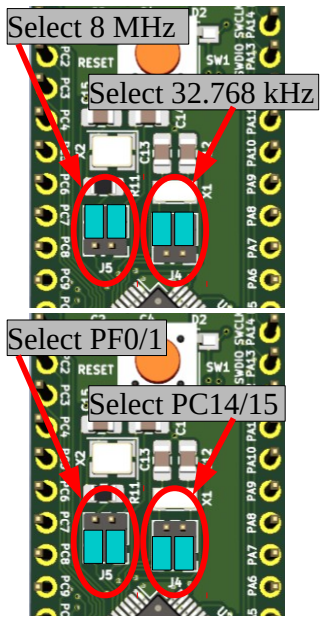
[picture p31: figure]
Select 8 MHz; Select 32.768 kHz; Select PF0/1; Select PC14/15

## Crystal Resonator Selection Shunts

The development board includes two high-precision crystal resonators. An 8 MHz resonator can be connected to microcontroller pins PF0 and PF1 to provide the high-speed external (HSE) clock reference. A 32.768 kHz resonator can be connected to pins PC14 and PC15 to provide the low-speed external (LSE) clock reference. Each of these pins can alternately be used as general-purpose I/O. The function of the pins is selected by inserting shunts into the J4 and J5 6-pin 1.27 mm headers. The development board can run with all jumpers removed so that PC14, PC15, PF0, and PF1 are not connected.

## Programming the Development Board

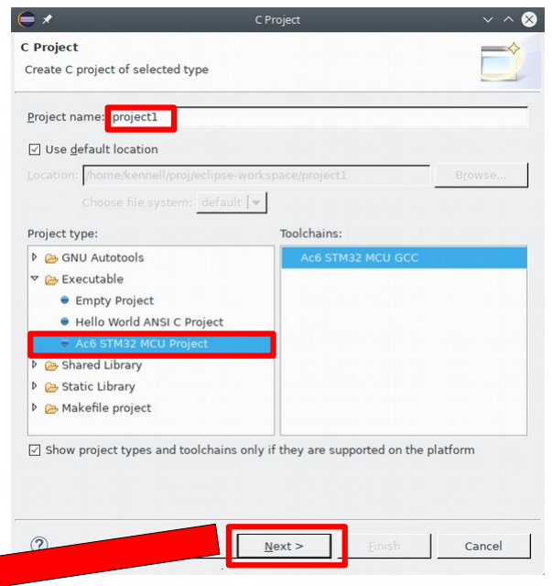
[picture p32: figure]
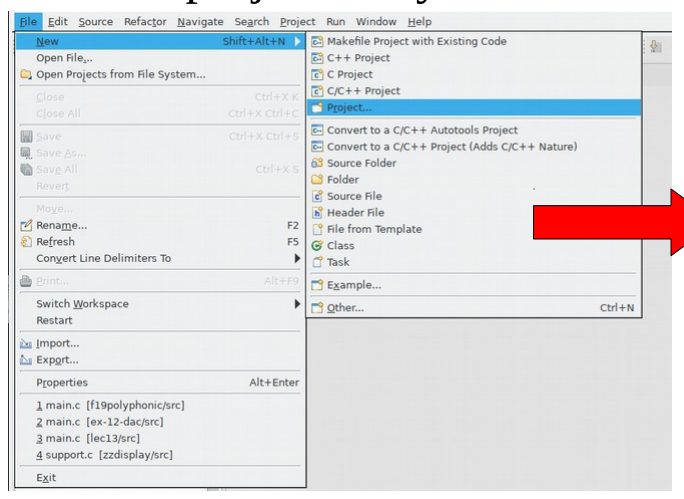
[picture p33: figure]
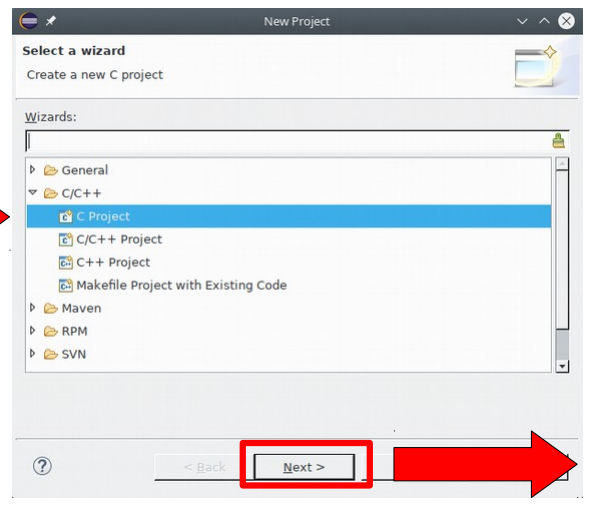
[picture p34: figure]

Create a project in SystemWorkbench:

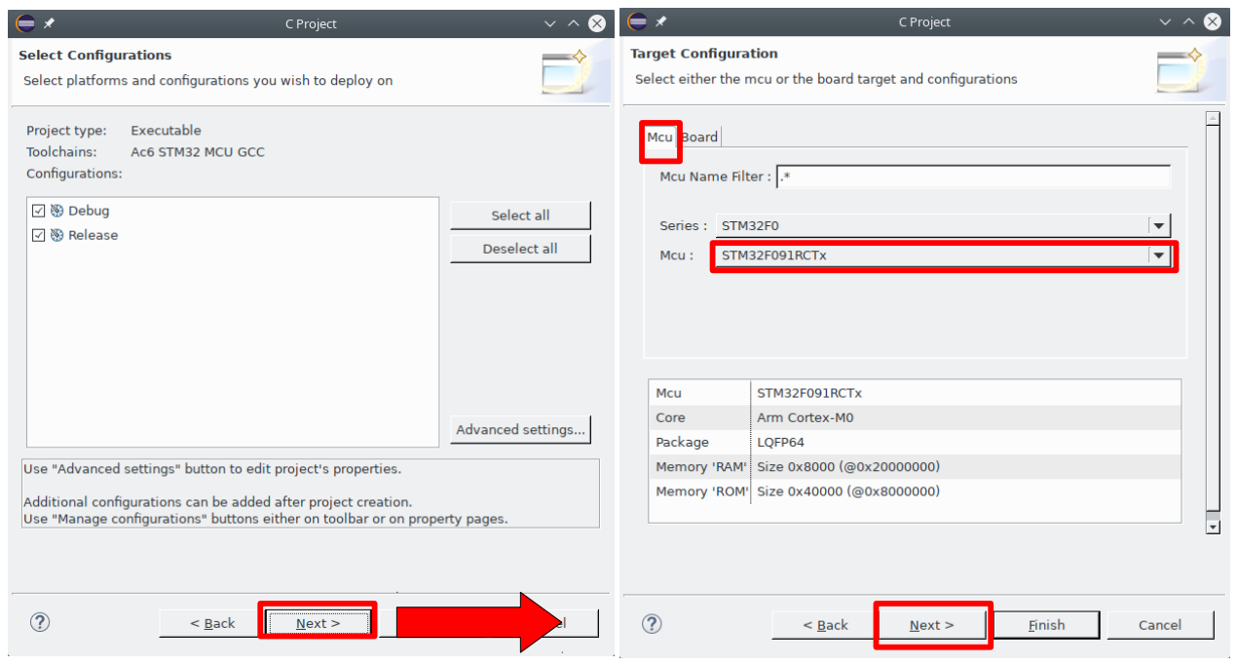
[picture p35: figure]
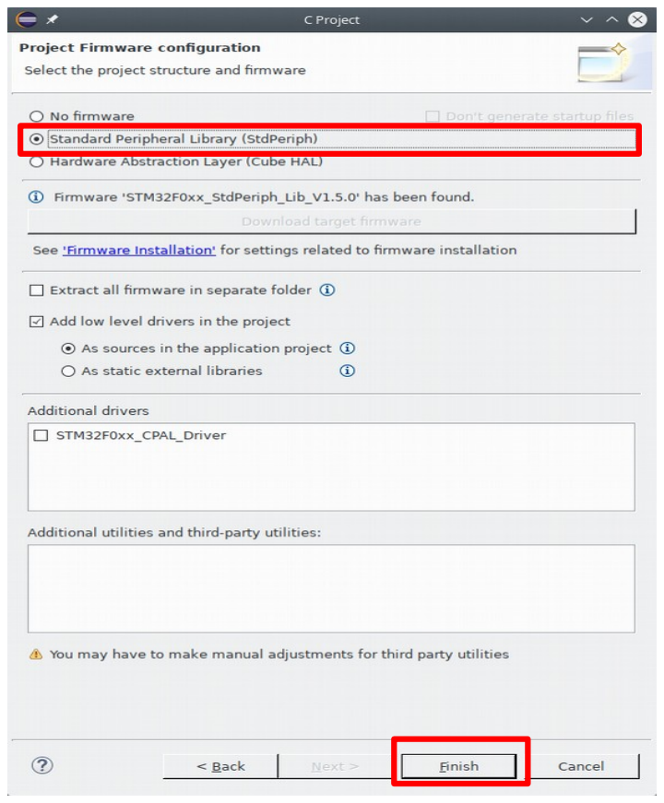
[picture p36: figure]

## Example Program

## Configure the USB ST-LINK V2 Programmer

The USB ST-LINK V2 Programmer uses a two-wire SWDIO/SWCLK protocol to interact with the STM32F091 microcontroller. It does not use the reset pin. SystemWorkbench must be configured to use "Software system reset" instead of "Connect under reset", which is the default for ST microcontrollers. To do this, compile your program and select the Run => Run Configurations menu so that the following dialog appears:

#include "stm32f0xx.h"

int main(void)
{
RCC->AHBENR |= RCC_AHBENR_GPIOCEN; GPIOC->MODER |= 0x55 << 12; for(;;) {
GPIOC->ODR ^= 0x3c0;
for(int x=0; x<1000000; x++) ;
}
}

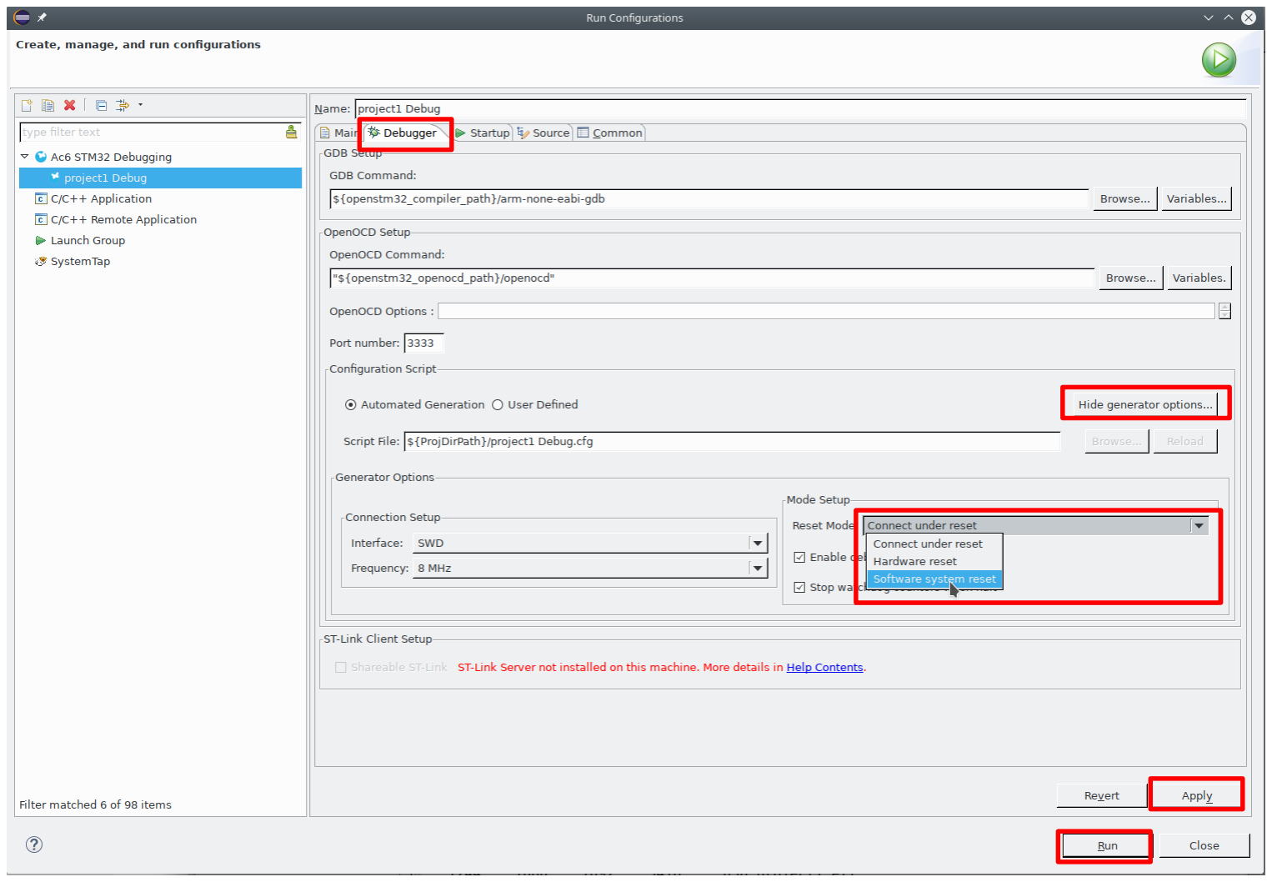
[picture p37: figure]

Common Problems
Recovering from modification of Port A 13/14 mode: The USB programmer does not use the reset line. Instead, it uses a software system reset that involves a special signal imposed on SWDIO and SWCLK. These two signals are handled with pins PA13 and PA14 of the STM32F091. If the PORTA MODER values for these pins are changed, the microcontroller cannot be programmed, debugged, or reset by the USB programmer. No damage done. To recover, change the program configuration, and hold the Reset button while programming the microcontroller.
Do not use Port C pins 13/14/15 as outputs: Pins PC13, PC14, and PC15 are controlled by a lowpower subsystem of the STM32F091. Connections to PC14 and PC15 are selected by shunts in header J4, but PC13 is always connected to a boundary pin on the development board. If any of these pins is configured for output and source or sink more than 3 mA, the driver for the low-speed external (LSE) crystal resonator will be permanently damaged. (See the obscure footnote 1 of Table 13 on page 40 of the STM32F091xBC datasheet.) Thereafter, the pins will still be useful for (low-current) GPIO. Only the oscillator will be damaged. There is no way to repair the oscillator once damaged. It is possible to build an external oscillator that is just as good, but not as convenient.

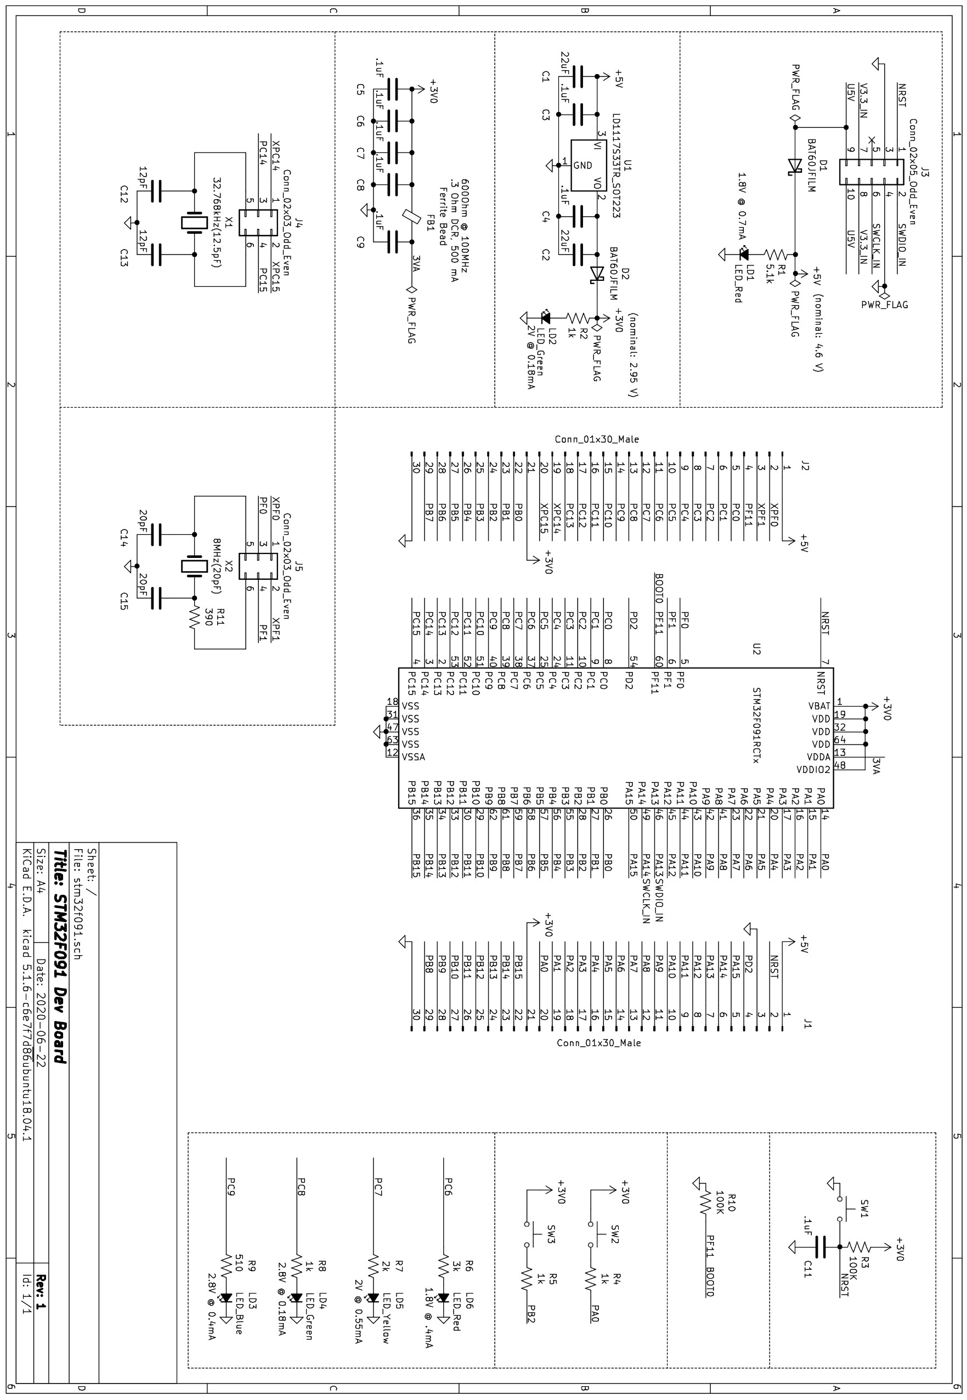
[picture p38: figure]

Revision History:
1.01: 23-Feb-2021, Corrected LD3 – LD6 names on front page summary.

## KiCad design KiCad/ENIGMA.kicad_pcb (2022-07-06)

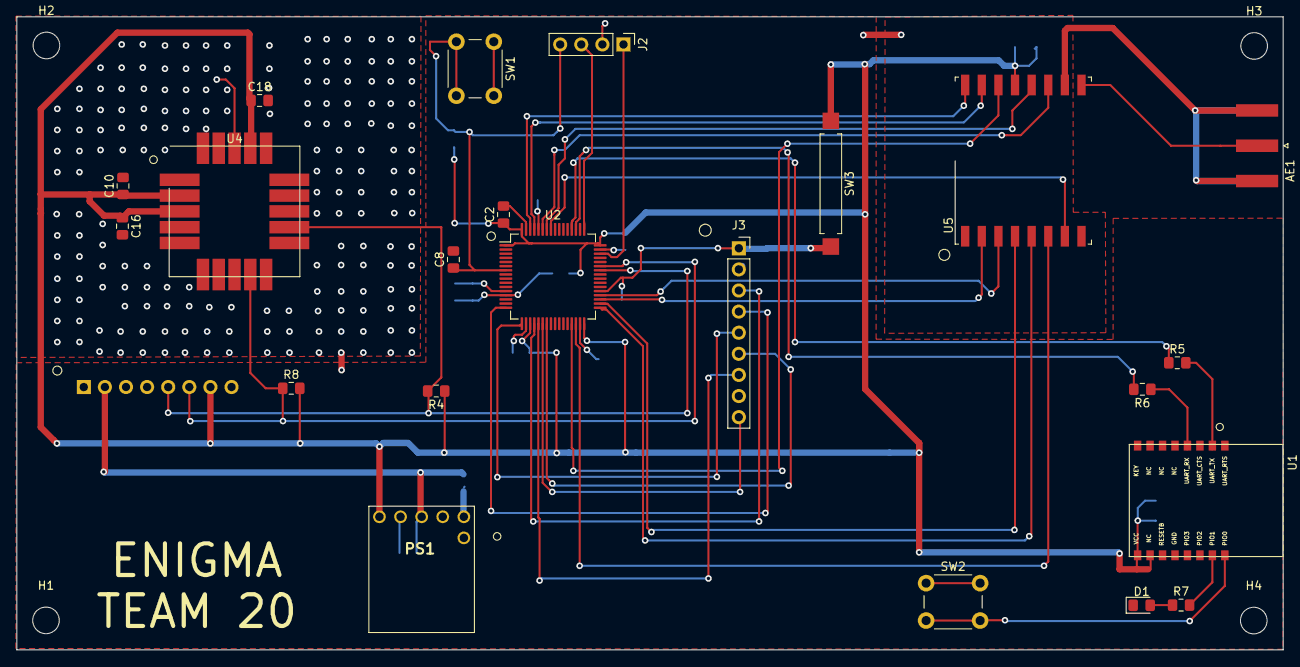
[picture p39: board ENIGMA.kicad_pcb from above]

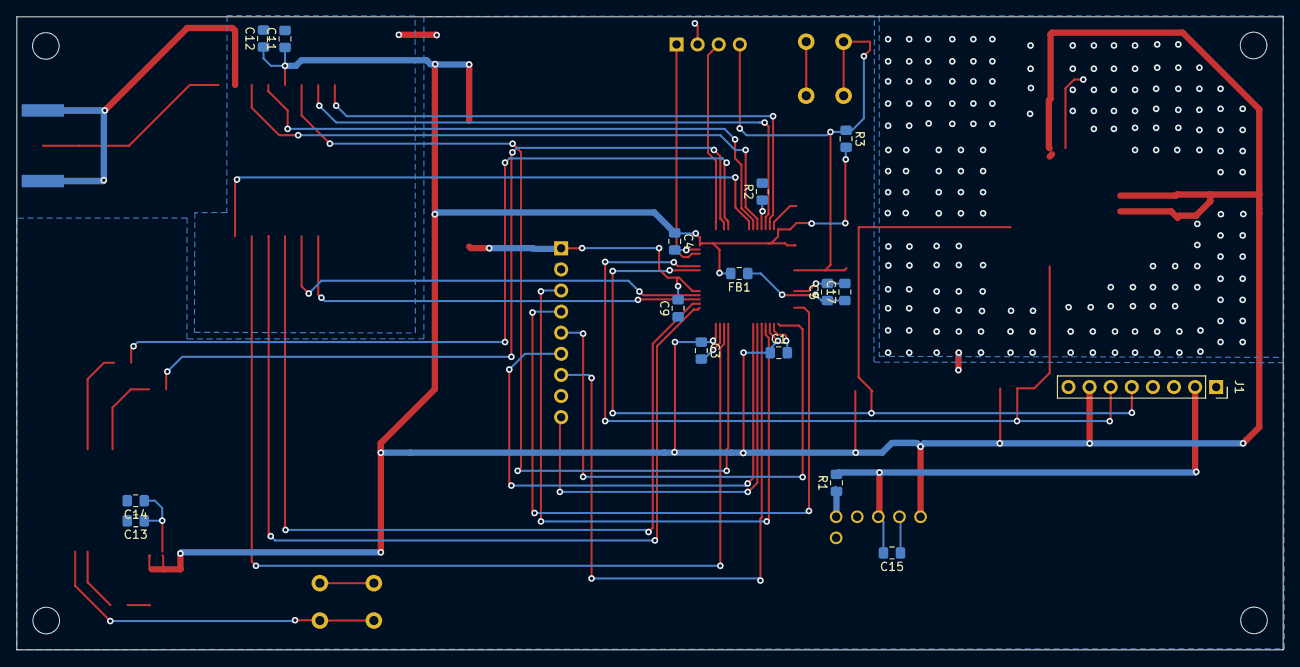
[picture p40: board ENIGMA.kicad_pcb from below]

Board: 2 copper layers, 152.4 x 76.2 mm, 42 parts (16 on the bottom side), 37 nets.

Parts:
AE1: Antenna_Shield; SMA_Amphenol_132289_EdgeMount
C1, C2, C3, C4, C5, C8, C9, C10, C11, C13, C17: .1 uF; C_0805_2012Metric_Pad1.15x1.40mm_HandSolder
C12, C15, C16, C18: 4.7 uF; C_0805_2012Metric_Pad1.15x1.40mm_HandSolder
C14: 10 uF; C_0805_2012Metric_Pad1.15x1.40mm_HandSolder
D1: LED; LED_0805_2012Metric_Pad1.15x1.40mm_HandSolder
FB1: 600 Ohm @ 100MHz .3Ohm DCR, 500mA Ferrite Bead; L_0805_2012Metric_Pad1.15x1.40mm_HandSolder
H1, H2, H3, H4: MountingHole; MountingHole_3.2mm_M3
J1: Conn_01x08_Female; PinSocket_1x08_P2.54mm_Vertical
J2: Conn_01x04_Male; PinHeader_1x04_P2.54mm_Vertical
J3: Conn_01x09_Female; PinSocket_1x09_P2.54mm_Vertical
PS1: S9V11F3S5C3
R1, R5, R6: 1K; R_0805_2012Metric_Pad1.15x1.40mm_HandSolder
R2, R3, R4, R8: 100K; R_0805_2012Metric_Pad1.15x1.40mm_HandSolder
R7: 470; R_0805_2012Metric_Pad1.15x1.40mm_HandSolder
SW1, SW2: SW_Push_Dual_x2; SW_PUSH_6mm
SW3: SW_DIP_x01; SW_SPST_REED_CT10-XXXX-G1
U1: HM-19_Bluetooth; hm19_Bluetooth
U2: STM32F091RCTx; LQFP-64_10x10mm_P0.5mm
U4: ublox_SAM-M8Q
U5: RFM69HCW; HOPERF_RFM69HW

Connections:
+3V0: C1.1, C2.1, C3.1, C4.1, C10.1, C11.1, C12.1, C13.1, C14.1, C16.1, C18.1, FB1.2, J1.7, PS1.6, R3.2, R4.1, R8.2, SW3.2, U1.9, U1.10, U2.1, U2.19, U2.32, U2.48, U2.64, U4.2, U4.3, U4.17, U5.13
+5V: C15.2, J1.2, PS1.4, R1.2
/3VA: C5.1, C17.1, FB1.1, U2.13
/NRST: C8.1, J2.4, R3.1, SW1.2, U2.7
/PA2: J3.4, U2.16
/PA3: J3.5, U2.17
/PA4: J3.3, U2.20
/PA5: J3.7, U2.21
/PA6: J3.9, U2.22
/PA7: J3.6, U2.23
/PA9: J1.5, R4.2, U2.42, U4.12
/PA10: J1.6, R8.1, U2.43, U4.9
/PB5: U2.57, U5.7
/PB6: U2.58, U5.12
/PB7: U2.59, U5.11
/PB8: U2.61, U5.15
/PB9: U2.62, U5.16
/PB10: U2.29, U5.14
/PB11: U2.30, U5.6
/PB12: U2.33, U5.5
/PB13: U2.34, U5.4
/PB14: U2.35, U5.2
/PB15: U2.36, U5.3
/PC6: C9.2, J3.1, SW3.1, U2.37
/PC10: R6.2, U2.51
/PC11: R5.1, U2.52
BOOT0: R2.1, U2.60
GND: AE1.2, C1.2, C2.2, C3.2, C4.2, C5.2, C8.2, C9.1, C10.2, C11.2, C12.2, C13.2, C14.2, C15.1, C16.2, C17.2, C18.2, D1.1, J1.1, J2.2, J3.2, PS1.1, PS1.5, R2.2, SW1.1, SW2.1, U1.12, U2.12, U2.18, U2.31, U2.47, U2.63, U4.1, U4.4, U4.5, U4.6, U4.10, U4.11, U4.15, U4.16, U4.20, U5.1, U5.8, U5.10
unnamed: AE1.1, U5.9
unnamed: D1.2, R7.1
unnamed: PS1.2, R1.1
unnamed: R5.2, U1.2
unnamed: R6.1, U1.4
unnamed: R7.2, U1.15
unnamed: SW2.2, U1.16
SWCLK: J2.3, U2.49
SWDIO: J2.1, U2.46

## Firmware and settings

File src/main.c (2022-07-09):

/**
  ******************************************************************************
  * @file    main.c
  * @author  Brian Dye
  * @version V1.0
  * @date    01-January-2022
  * @brief   STP Switch Initialization, Serial Communication enable,
             Setup and Enable Interrupts, Interrupt Service Routines,
             GPS and Battery Moniter Helper Functions
  ******************************************************************************
*/


#include "stm32f0xx.h"
#include <stdio.h>
#include <stdlib.h>
#include <string.h>
#include <lcd.h>
#include <I2C.h>
#include <bluetooth.h>
#include <RFM69.h>
#include <RFM69registers.h>
#include <SPI.h>
#include <STPswitch.h>




STPswitch * switchNode;
uint8_t USART4_Buffer_Rx[71];
char latitude[20] = {0};
char longitude[20] = {0};
uint8_t soc;
uint8_t nodeAddress;


uint16_t StateOfCharge(void) {
  // Send two byte command for state of charge
  uint8_t command[2] = {0x1c, 0x1d};
  if (I2C_Send(I2C1, FUELGAUGE, &(command[0]), 1) == -1) {
      return 0;
  }
  //I2C_Send(I2C1, FUELGAUGE, &(command[1]), 1);


  // Read two byte from fuel gauge
  uint8_t data[2] = {0};                            // State of Charge (SOC)
  I2C_Receive(I2C1, FUELGAUGE, data, 2);

  // Return State of Charge
  return ((uint16_t) data[1] << 8) | data[0];

}



uint8_t get_coord(char * lat, char * lon) {
      uint8_t data[35] = {0};
      char* flag;
      char* temp;
      char* degree;
      char* orient;
      size_t len;
      uint8_t DATA_STREAM = 0xFF;

      if (I2C_Send(I2C1, 0x42, &DATA_STREAM, 1) != 0) {return 0;}
      if (I2C_Receive(I2C1, 0x42, data, 20) != 0) {return 0;}

      flag = strtok((char*)data, ",");
      // TODO: parse the data
      if(*flag == 36){  // 36 --> "$"
          flag = strtok(NULL, ",");
          flag = strtok(NULL, ",");
          if(*flag == 65){  // 65 --> "A"
              // move the rest of the string to the string lat and lon
              degree = strtok(NULL, ",");
              orient = strtok(NULL, ",");
              strcat(degree, orient);
              len = strlen(degree);
              strcpy(lon, degree);
              strcat(lon, "\n");
              degree = strtok(NULL, ",");
              orient = strtok(NULL, ",");
              strcat(degree, orient);
              len = strlen(degree);
              strcpy(lat, degree);
              strcat(lat, "\n");
              return 1;
          }
      }
      return 0;
  }





// Periodically poll battery and GPS coordinates
// Send a control packet
////////////////////////////////////
void TIM6_DAC_IRQHandler(void)
{

    uint8_t value = StateOfCharge();
    if (value > 0 && value <= 100) {
        soc = value;
    }
    get_coord( latitude, longitude);

    sendControlPacket(switchNode);

    // Reset Timer 6 seconds
    TIM6->SR = 0;

}


void setup_tim6(void)
{
  RCC->APB1ENR |= (1<<4);           // Enable timer 6 clock
  TIM6->PSC = 11999;                  // Set precale value
  TIM6->ARR = 3999;                   // ARR Value
  TIM6->CR1 &= ~TIM_CR1_DIR;

  TIM6->DIER |= TIM_DIER_UIE;       // Set the UIE bit in the DIER register
  TIM6->CR1 |= TIM_CR1_CEN;         // Set CEN bit of TIM6 CR1
  //NVIC->ISER[0] = (1<<TIM6_DAC_IRQn);  // Update NVIC ISER for timer 6
  NVIC_SetPriority(TIM6_DAC_IRQn, 3);
  NVIC_EnableIRQ(TIM6_DAC_IRQn);
}



void EXTI4_15_IRQHandler(void) {
  // -------------------------------------------
  // LCD interrupt handler
  // -------------------------------------------
  if ((EXTI->PR & EXTI_PR_PR6) == EXTI_PR_PR6) {
                                           // Setup SP1 for LCD
      // Initialize the LCD
      LCD_Init();
      LCD_Clear(WHITE);
      LCD_Circle(230, 275, 8, 0, BLACK);
      LCD_DrawFillRectangle(220, 252, 229, 297,  WHITE);

      // Draw Battery Outline
      LCD_DrawRectangle(10, 300, 230, 250, BLACK);


      // Get Battery Level and Display it
      float level = 212.0 * soc / 100.0 + 15;
      LCD_DrawFillRectangle( 14, 254, (u16) level, 295,  0x07ED);



      // Network Status
      char * p = "Status:";
      LCD_DrawString(90, 20, BLACK, WHITE, p, 20, 0);
      LCD_DrawFillRectangle( 0, 35, 240, 45,  WHITE);
      if (switchNode->connected) {
          char * q = "Connected to Network";
          LCD_DrawString(15, 50, 0x07E8, BLACK, q, 22, 0);
          LCD_DrawFillRectangle( 15, 67, 240, 95,  WHITE);
      } else {
          char * q = "Not Connected";
          LCD_DrawString(50, 50, RED, BLACK, q, 25, 0);
          LCD_DrawFillRectangle( 15, 67, 240, 95,  WHITE);
      }


      // GPS Location:
      char * r = "Current Location:";
      LCD_DrawString(30, 90, BLACK, WHITE, r, 22, 0);
      LCD_DrawFillRectangle( 30, 107, 240, 120,  WHITE);


      // Valid Cordinates Received
      LCD_DrawString(60, 115, BLUE, BLACK, latitude, 22, 0);
      LCD_DrawFillRectangle( 60, 130, 169, 150,  BLACK);

      LCD_DrawString(60, 135, RED, BLACK, longitude, 22, 0);
      LCD_DrawFillRectangle( 60, 152, 169, 180,  WHITE);


      EXTI->PR |= EXTI_PR_PR6;


  // ----------------------------------------------------
  // RFM69 Packet received interrupt handler
  // ----------------------------------------------------
  } else if ((EXTI->PR & EXTI_PR_PR10) == EXTI_PR_PR10) {
      uint8_t packet[74] = {0};
      uint8_t packetSize = RFM69_handleReceivedPacket(packet);

      if (packetSize > 0) {
          // Packet needs to be ROUTED
          // Clear interrupt
          EXTI->PR |= EXTI_PR_PR10;
          handlePacket(switchNode, packet, packetSize);
      } else {
          // False Alarm
          // Clear interrupt
          EXTI->PR |= EXTI_PR_PR10;
      }



  }

}



void DMA1_CH4_5_6_7_DMA2_CH3_4_5_IRQHandler(void) {
  if ( ((DMA1->ISR & DMA_ISR_HTIF6) == DMA_ISR_HTIF6)) {

      //uint8_t value = USART4->RDR; // Reading RDR clears the RXNE flag
      // Read Command
      char command[8] = {0};
      nano_wait(10000000);
      memcpy(command, (char *) USART4_Buffer_Rx, 8);


      // From command take action
      if (strncmp(command, "get+ft", 6) == 0) {
          USART4_Write ((uint8_t *) "Forwarding Table:\nA\nB\nC\n", 24);
          ListNode * p = switchNode->forwarding_table->head;
          char data[2] = {'\n'};
          while (p != NULL) {
              data[0] = p->key;
              USART4_Write ((uint8_t *) data, 2);
              p = p->next;
          }
          USART4_Write ((uint8_t *) "\n", 1);


      } else if (strncmp(command, "get+gps", 7) == 0) {
          if (latitude[0] != 0 ) {

              // Send Latitude
              USART4_Write ((uint8_t *) latitude, 11);

              //DMA_Transmit(latitude, 11);

              // Send Longitude
              USART4_Write ((uint8_t *) longitude, 11);

          //DMA_Transmit(longitude, 11);
          } else {
              USART4_Write ((uint8_t *) "No Coordinates Available\n", 25);
              //DMA_Transmit((uint8_t *) "Error: No Cordinates", 20);
          }

      } else if (strncmp(command, "get+bat", 7) == 0) {
          char data[3] = {'\n'};
          sprintf(data, "%2d", soc);
          data[2] = '\n';
          USART4_Write ((uint8_t *) data, 3);
          //DMA_Transmit((uint8_t *) data, 3);



        } else if (strncmp(command, "UDP+Pack", 8) == 0) {
              uint8_t * START = &(USART4_Buffer_Rx[10]);
              uint8_t nn[2] = {0};
              nano_wait(10000000);
              memcpy(nn, &(USART4_Buffer_Rx[8]), 2);
              uint8_t packetSize = atoi((const char *) nn);
              uint8_t packet[74] = {0};
              nano_wait(10000000);
              memcpy(&(packet[2]), START, packetSize);
              packet[5] = packetSize;
              // handle received packet from data link layer
              // RFM69_sendPacket((uint8_t) 'B', DATA_PACKET, packet, strlen(packet));
              //RFM69_sendPacket((uint8_t) packet[1], DATA_PACKET, packet, packetSize);
              handlePacket(switchNode, packet, packetSize);


        } else if (strcmp(command, "reset") == 0) {
              return;

        } else if (command[0] == 'O' && command[1] == 'K') {
            // Bluetooth module has status update



        } else {
            //USART4_Write ((uint8_t *) "Error: Incorrect Command\n", 24);
            //DMA_Transmit((uint8_t *) "Error: Incorrect Command\n", 24);
        }


        // Write 1 to clear the corresponding TCIF flag
        DMA1->IFCR |= DMA_IFCR_CHTIF6;
        DMA1_Channel6->CCR &= ~DMA_CCR_EN;                     // Disable DMA channel
        DMA1_Channel6->CNDTR = 62;
        DMA1_Channel6->CCR |= DMA_CCR_EN;                     // Enable DMA channel


  }


}


void SYSTEM_SLEEP(void) {
  NVIC_DisableIRQ(TIM6_DAC_IRQn);
  NVIC_DisableIRQ(7);
  NVIC_DisableIRQ(USART3_8_IRQn);
  RFM69_Sleep();
  HM19_Sleep();
  DMA1_Channel7->CCR &= ~DMA_CCR_EN;              // Disable DMA1 channel7
  DMA1_Channel6->CCR &= ~DMA_CCR_EN;              // Disable DMA1 channel6
  USART4->CR1 &= ~USART_CR1_UE;                   // Disable USART4
  SPI1->CR1 &= ~SPI_CR1_SPE;                      // Disable SPI1
  SPI2->CR1 &= ~SPI_CR1_SPE;                      // Disable SPI2
  I2C1->CR1 &= I2C_CR1_PE;                        // Disable I2C1
  while (1) {
      __WFI();
  }


}

void RFM69_TESTsender() {
  uint8_t packet[9] = {nodeAddress, RF69_BROADCAST_ADDR, 0, 9, 'H', 'e', 'l','l', 'o'};
  while (1) {
      RFM69_sendPacket(RF69_BROADCAST_ADDR, DATA_PACKET, packet, 9);
      nano_wait(200000000);
  }
}


void RFM69_TESTreceiver(void) {
  RFM69_setMode(RF69_MODE_RX);
  while (1) {
      __WFI();
  }
}

int main(void) {
  nodeAddress = (uint8_t) 'A';
  switchNode = createSTPswitch(nodeAddress);      // Initialize the Switch
  SPI(SPI1);
  LCD_EXTI6_Initialize();                         // LCD Interrupt Enable
  I2C_Initialization(I2C1);                       // GPS and Fuel Gauge

  //HM19_init();
  //HM19_Sleep();

  RFM69_reset();
  if (RFM69_initialize(nodeAddress, 6) != 1) {     // Node address, network ID
      return 1;
  } else {
      USART(USART4);
      setup_tim6();



  }

}


  //SPI(SPI1);
  //I2C_Initialization(I2C1);
  //setup_tim6();
  //USART(USART4);
  //char str[] = "Hello Brian";
  //USART_Write(USART4, (uint8_t *) str, strlen(str));







    /*
    uint8_t USART4_Buffer_Rx[BufferSize] = {0};
    uint32_t Rx4_Counter = 0, Tx4_Counter = 0;

    USART(USART4, USART4_Buffer_Rx);                // Setup UART for Bluetooth
    SPI(SPI2);                                      // Setup SPI2 for RFM69
    SPI(SPI1);                                      // Setup SPI1 for LCD


    //uint8_t * txBuffer = (uint8_t *) "AT";
    //USART_Write(USART4, txBuffer, 2);

    //uint8_t * tx1Buffer = (uint8_t *) "AT+ROLE0";
    //USART_Write(USART4, tx1Buffer, 8);

    // Send a Packet using RFM69
    RFM69_reset();
    if (RFM69_initialize(RF69_915MHZ, 'A', 6) != 1) {    // Node address, network ID
          return 1;
    } else {
        uint8_t VALUE = RFM69_readReg(REG_BITRATEMSB);
        uint8_t * buffer = "Hello this is a test";
        for (int i = 0; i< 100; i++){
            RFM69_send((uint8_t) 'B' , USART4_Buffer_Rx, 20, 0);
        }
    }
    LCD_Init();
    LCD_Clear(BLACK);


    return 0;
    */

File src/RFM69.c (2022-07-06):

#include "RFM69.h"
#include "RFM69registers.h"
#include "SPI.h"
#include "stm32f0xx.h"
#include <time.h>





static volatile uint8_t nodeAddress;
static uint8_t _powerLevel = 31;


void RFM69_interruptOFF(void) {
  NVIC_DisableIRQ(USART3_8_IRQn);
  NVIC_DisableIRQ(TIM6_DAC_IRQn);
  EXTI->IMR &= ~EXTI_IMR_MR10;
  NVIC_DisableIRQ(7);
}

void RFM69_interruptON(void) {
  EXTI->IMR |= EXTI_IMR_MR10;
  NVIC_EnableIRQ(USART3_8_IRQn);
  NVIC_EnableIRQ(7);
  NVIC_EnableIRQ(TIM6_DAC_IRQn);
}


// function to control the GPIO tied to RFM69 chip select (parameter HIGH or LOW)
void RFM69_SetCSPin(uint8_t value) {
  if (value == 1) {
        GPIOB->ODR |= 0x1000;
    } else {
        GPIOB->ODR &= ~0x1000;
    }
}

void RFM69_select(void) {
  //interruptOFF();
  RFM69_SetCSPin(0);
}

void RFM69_unselect(void) {
  RFM69_SetCSPin(1);
  //interruptON();
}

// function to read GPIO connected to RFM69 DIO0 (RFM69 interrupt signalling)
uint16_t RFM69_ReadDIOPin(uint8_t pin) {
  switch (pin){
        case 0:
          return GPIOB->IDR & (1<<10);
          break;
        case 2:
          return GPIOB->IDR & (1<<9);
          break;
        case 5:
          return GPIOB->IDR & (1<<5);
          break;
        default:
          return 0;
  }
}

uint16_t RFM69_ModeReady(void) {
  return RFM69_ReadDIOPin(5);
}



// function to transfer 1byte on SPI with readback
uint8_t SPI_transfer8(uint8_t value) {

  uint8_t valueRead = 0;
  //*(uint8_t *)&(SPI2->DR) = value;
  SPI_Write(SPI2, &value, &valueRead, 1);
  return valueRead;

}

uint8_t RFM69_readReg(uint8_t addr)
{
  uint8_t regval;
  RFM69_select();
  SPI_transfer8(addr & 0x7F);
  regval = SPI_transfer8(0);
  RFM69_unselect();
  return regval;
}

void RFM69_writeReg(uint8_t addr, uint8_t value)
{
  RFM69_select();
  SPI_transfer8(addr | 0x80);
  SPI_transfer8(value);
  RFM69_unselect();
}








// return the frequency (in Hz)
uint32_t RFM69_getFrequency()
{
  return RF69_FSTEP * (((uint32_t) RFM69_readReg(REG_FRFMSB) << 16) + ((uint16_t) RFM69_readReg(REG_FRFMID) << 8) + RFM69_readReg(REG_FRFLSB));
}



void RFM69_setMode(uint8_t newMode)
{

  switch (newMode) {
    case RF69_MODE_TX:
      // Turn on Transmitter
      RFM69_writeReg(REG_OPMODE, (RFM69_readReg(REG_OPMODE) & 0xE3) | RF_OPMODE_TRANSMITTER);
      if (ISRFM69HW) RFM69_setHighPowerRegs(1);
      break;
    case RF69_MODE_RX:
      // Turn on the receiver
      // set DIO0 to "PAYLOADREADY" in receive mode
      RFM69_writeReg(REG_DIOMAPPING1, RF_DIOMAPPING1_DIO0_01);

      RFM69_writeReg(REG_OPMODE, (RFM69_readReg(REG_OPMODE) & 0xE3) | RF_OPMODE_RECEIVER);
      if (ISRFM69HW) RFM69_setHighPowerRegs(0);
      break;
    case RF69_MODE_SYNTH:
      RFM69_writeReg(REG_OPMODE, (RFM69_readReg(REG_OPMODE) & 0xE3) | RF_OPMODE_SYNTHESIZER);
      break;
    case RF69_MODE_STANDBY:
      RFM69_writeReg(REG_OPMODE, (RFM69_readReg(REG_OPMODE) & 0xE3) | RF_OPMODE_STANDBY);
      break;
    case RF69_MODE_SLEEP:
      RFM69_writeReg(REG_OPMODE, (RFM69_readReg(REG_OPMODE) & 0xE3) | RF_OPMODE_SLEEP);
      break;
    default:
      return;

  }


  // Wait for ModeReady
  while (!RFM69_ModeReady());


}

//put transceiver in sleep mode to save battery - to wake or resume receiving just call RFM69_receiveDone()
void RFM69_Sleep(void) {
  RFM69_setMode(RF69_MODE_SLEEP);
}

//set this node's address
void RFM69_setAddress(uint8_t addr)
{
  RFM69_writeReg(REG_NODEADRS, addr);
}

//set this node's network id
void RFM69_setNetwork(uint16_t networkID)
{
  RFM69_writeReg(REG_SYNCVALUE1, (uint8_t)(networkID & 0x00FF));
  RFM69_writeReg(REG_SYNCVALUE2, (uint8_t)(networkID >> 8));
}

// set *transmit/TX* output power: 0=min, 31=max
// this results in a "weaker" transmitted signal, and directly results in a lower RSSI at the receiver
// the power configurations are explained in the SX1231H datasheet (Table 10 on p21; RegPaLevel p66): http://www.semtech.com/images/datasheet/sx1231h.pdf
// valid powerLevel parameter values are 0-31 and result in a directly proportional effect on the output/transmission power
// this function implements 2 modes as follows:
//       - for RFM69W the range is from 0-31 [-18dBm to 13dBm] (PA0 only on RFIO pin)
//       - for RFM69HW the range is from 0-31 [5dBm to 20dBm]  (PA1 & PA2 on PA_BOOST pin & high Power PA settings - see section 3.3.7 in datasheet, p22)
void RFM69_setPowerLevel(uint8_t powerLevel)
{
  _powerLevel = (powerLevel > 31 ? 31 : powerLevel);
  if (ISRFM69HW)
  {
    _powerLevel /= 2;
  }
  RFM69_writeReg(REG_PALEVEL, (RFM69_readReg(REG_PALEVEL) & 0xE0) | _powerLevel);
}




// To enable encryption: radio.encrypt("ABCDEFGHIJKLMNOP");
// To disable encryption: radio.encrypt(null) or radio.encrypt(0)
// KEY HAS TO BE 16 bytes !!!
void RFM69_encrypt(const char* key)
{
  RFM69_setMode(RF69_MODE_STANDBY);
  if (key != 0)
  {
    RFM69_select();
    SPI_transfer8(REG_AESKEY1 | 0x80);
    for (uint8_t i = 0; i < 16; i++)
      SPI_transfer8(key[i]);
    RFM69_unselect();
  }
  RFM69_writeReg(REG_PACKETCONFIG2, (RFM69_readReg(REG_PACKETCONFIG2) & 0xFE) | (key ? 1 : 0));
}


// get the received signal strength indicator (RSSI)
int16_t RFM69_readRSSI(uint8_t forceTrigger)
{
  int16_t rssi = 0;
  if (forceTrigger)
  {
    // RSSI trigger not needed if DAGC is in continuous mode
    RFM69_writeReg(REG_RSSICONFIG, RF_RSSI_START);


    while ((RFM69_readReg(REG_RSSICONFIG) & RF_RSSI_DONE) == 0x00); // wait for RSSI_Ready
  }
  uint8_t value = RFM69_readReg(REG_RSSICONFIG);
  rssi = RFM69_readReg(REG_RSSIVALUE);
  rssi >>= 1;
  return rssi;
}



// for RFM69HW only: you must call RFM69_setHighPower(true) after initialize() or else transmission won't work
void RFM69_setHighPower(uint8_t onOff) {
  RFM69_writeReg(REG_OCP, ISRFM69HW ? RF_OCP_OFF : RF_OCP_ON);
  if (ISRFM69HW) // turning ON
    RFM69_writeReg(REG_PALEVEL, (RFM69_readReg(REG_PALEVEL) & 0x1F) | RF_PALEVEL_PA1_ON | RF_PALEVEL_PA2_ON); // enable P1 & P2 amplifier stages
  else
    RFM69_writeReg(REG_PALEVEL, RF_PALEVEL_PA0_ON | RF_PALEVEL_PA1_OFF | RF_PALEVEL_PA2_OFF | _powerLevel); // enable P0 only
}

// internal function
void RFM69_setHighPowerRegs(uint8_t onOff)
{
  RFM69_writeReg(REG_TESTPA1, onOff ? 0x5D : 0x55);
  RFM69_writeReg(REG_TESTPA2, onOff ? 0x7C : 0x70);
}



uint8_t RFM69_readTemperature(uint8_t calFactor) // returns centigrade
{
  RFM69_setMode(RF69_MODE_STANDBY);
  RFM69_writeReg(REG_TEMP1, RF_TEMP1_MEAS_START);
  while ((RFM69_readReg(REG_TEMP1) & RF_TEMP1_MEAS_RUNNING));
  return ~RFM69_readReg(REG_TEMP2) + COURSE_TEMP_COEF + calFactor; // 'complement' corrects the slope, rising temp = rising val
} // COURSE_TEMP_COEF puts reading in the ballpark, user can add additional correction


void RFM69_rcCalibration()
{
  RFM69_writeReg(REG_OSC1, RF_OSC1_RCCAL_START);
  while ((RFM69_readReg(REG_OSC1) & RF_OSC1_RCCAL_DONE) == 0x00);
}
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

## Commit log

2022-07-06 KiCad PCB Design
    [ENIGMA.kicad_pcb, ENIGMA.kicad_sch, ENIGMA.sch]
2022-07-06 KiCad Directory
